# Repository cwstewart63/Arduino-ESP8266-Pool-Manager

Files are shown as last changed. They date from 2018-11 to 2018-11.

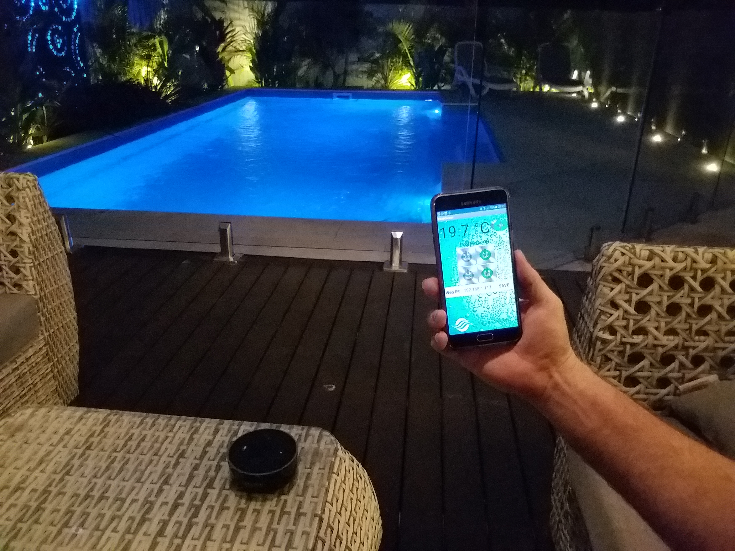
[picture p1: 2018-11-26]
MyPoolPic.jpg

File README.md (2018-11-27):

# Arduino-ESP8266-Pool-Manager
Pool manager with Phone App, Alexa, using Arduino and ESP8266

Project Summary:
This project is to allow remote control of my pool and associated lights with a dedicated display in the house, a phone application and Amazon Alexa. Any and/or all of these input devices may be used to control the pool. The pool temperature and the status of the control devices are monitored as additional information.

Folder Information:

123D Design: Contains Nextion 3.5" Display enclosure source file and .stl files of the bezel and base for 3D printing.
Note: the design uses M3 x 5mm brass inserts. 4 for the bezel, 4 for the base. Enclosure is sized to fit additional Modus Master PCB board which is the same size as the display using M3 x 6mm standoffs.

Alexa: Contains the AWS interaction model and the lambda function (python).
Note: Need to set up an Amazon AWS account and a developer account. lambda function needs to be updated with your thingspeak channel and key details

Arduino: Contains the Modbus Slave and Modbus Master source file and the ESP8266Modbus library.
Note: All code has been compiled using Arduino IDE Ver 1.8.4. Use the arduino IDE boards manager to install the ESP8266 range of boards.
This project has specifically used an Aduino nano for the Modbus Slave and an ESP8266 NodeMCU for the Modbus Master.
All libraries are standard as referenced with the excpetion of the ESP8266Modbus library which is the referenced Arduino Modbus library modified (ie just commented out specific Arduino references) so that it compiles in the ESP8266 environment.

MIT_AI2_PhoneApp: Contains the MIT App Inventor 2 project source and .apk file for android phone.
Note: Project can be converted to Thunkable if apple app is required. Note Port 81 has been explicitly used for the phone app server.

Nextion Display: Contains the nextion editor project source and the loadable .tft file for nextion
Note: This project uses the Nextion 3.5" enhance display with RTC for time / timer functions.

PCB Designs: Contains the PCB gerber files and Altium Circuitmaker source files for the Modbus Slave, Modbus Master, Astralpools VX Chlorinator interface board and an optional Valve power supply. The project uses a 24VAC 20VA transformer which will support one valve. If two valves are required then you can use this PCB design with a 24VAC 50VA transformer from the same manufacturer.
Note: All PCB designs were made using Altium Circuitmaker. I used breadboardkiller to manufacture the boards for me. Wiring schematics are included in case anyone wishes to reproduce their own boards.

Thingspeak: Note this project uses two thingspeak channels as the IOT interface for Amazon Alexa functionality, with the MQTT service for the publishing of status information and the subscibe service for the forwarding of Alexa command. The defualt in the code is for Alexa to be disabled. On configuration (ie. using Modbus Master board configuration pin), you enter your SSID, password details, along with the thinspeak channel details and tick the enable Alexa box.

Special thanks to those who provided the following libraries:

ModbusRTU: Samuel Marco i Armengol
https://github.com/smarmengol/Modbus-Master-Slave-for-Arduino

WiFi Manager: Ken Taylor
https://github.com/kentaylor/WiFiManager

Alexa Belkin Switch WEMO Emulator: Brian Lough
https://github.com/witnessmenow/esp8266-alexa-wemo-emulator

MQTT Client: Nick O'Leary
https://github.com/knolleary/pubsubclient

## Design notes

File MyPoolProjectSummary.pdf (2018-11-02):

# My Pool Project

## Contents

## Project Summary:

This project is to allow remote control of my pool and associated lights with a dedicated display in the house, a phone application and Amazon Alexa. Any and/or all of these input devices may be used to control the pool. The pool temperature and the status of the control devices are monitored as additional information.

The base system installed by the pool company consisted of an AstralPools VX chlorinator and a Viron P320 multispeed pump. To turn on the spa for example you had to go to the pool equipment enclosure and manually change the pool mode from “auto” to “on”, turn the valve to direct water to the spa, and manually set the pump speed to “high”.

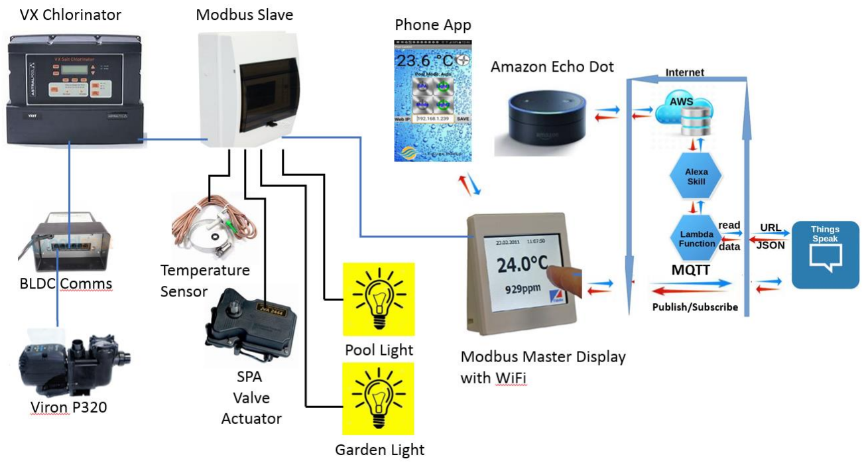
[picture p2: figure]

The schematic above shows the logical connectivity of the systems, which can be divided into three fundamental categories being, the standard Astralpools functionality, the Modbus Slave local control device and the Modbus Master remote display device.

## Standard AstralPools Functionality

The first stage of the project is to enable communication between the VX chlorinator and the Viron multispeed pump. This is achieved by the addition of the Viron BLDC communications module. Once installed you need to:
1. Enable “Fast Comms” on the Viron pump.
2. Enable “Fast Comms” on the VX chlorinator.
3. Select “3 speed pump enable” on the VX chlorinator.

Once this is done additional configuration menus on the VX chlorinator are shown which enable the operator to associate the desired pump speed with the mode of operation. In this case for normal chlorination (pool mode auto), then a low speed 1 is desired, while when spa operation (pool mode on) is requested, then high speed 3 is desired.
Note: The communications between the VX chlorinator and viron pump in Australia is not MODBUS. Although Astralpools in Europe does support the viron pump with MODBUS, the Australian version is a proprietary protocol.

## MODBUS Slave Local Control Device

The local control device is installed in the pool equipment enclosure adjacent to the VX chlorinator and viron pool pump. This device is essentially a Arduino Nano microcontroller which supports the inputs (temperature and pool status) and the digital outputs for the valves and lights. The microcontroller is also programmed as a Modbus slave for communication to the Modbus master display controller.
The microcontroller is programmed using the Arduino IDE software on windows.

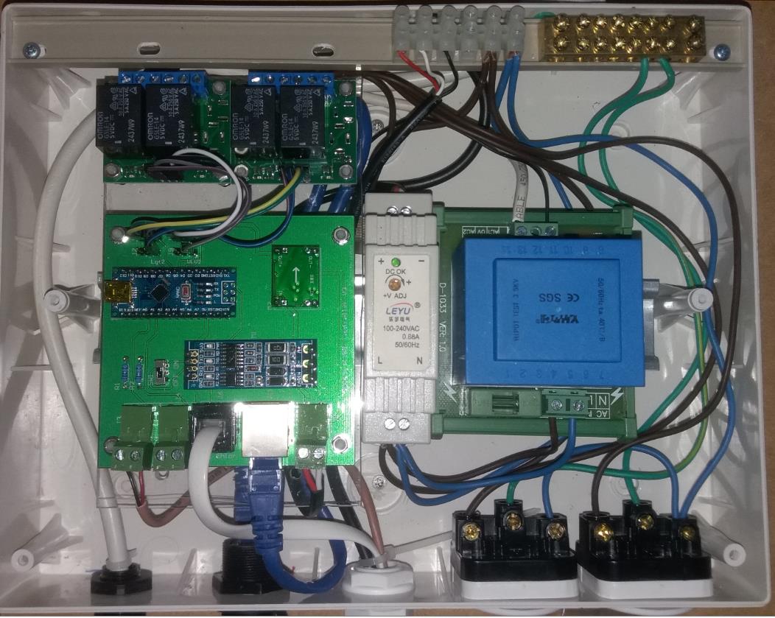
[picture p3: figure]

The major components of the Modbus slave local controller include:
1. Arduino Nano microcontroller PCB
2. 24VDC power supply (power for both local controller, interface module and remote display controller)
3. 24VAC power supply for Jandy valve actuator
4. 4 x Relay modules for the valve and lights control
5. A standard 12 pole IP54 electrical enclosure with DIN rail mounting
6. 2 x panel mounted electrical sockets for the light connections.

In addition there is a VX Chlorinator interface module PCB (below) which is installed into the chlorinator itself to provide the local I/O control and connected to the Modbus slave local controller via a standard RJ12 six core cable.

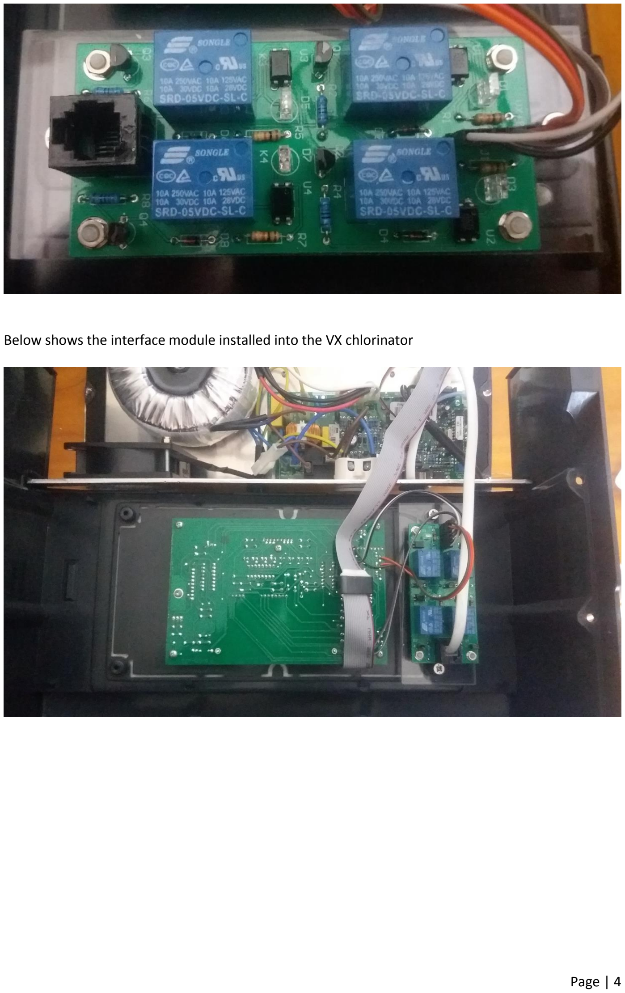
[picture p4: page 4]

Below shows the interface module installed into the VX chlorinator

## MODBUS Master Remote Display Device

The Remote display device is a 3.5 inch Nextion touch screen mounted into a custom 3D printed enclosure to house the touch screen and the Modbus master PCB. Power and communications are provided by a standard RJ45 CAT5e network cable connected to the Modbus slave controller. Modbus communications are via one pair of the CAT5e cable using RS485 communication modules with two pairs being used for the 24VDC power.

The display allows the remote monitoring and control of all the connected pool devices. In addition the display also has two timers associated with the lights to enable automatic on/off control of the lights. The timers in the VX Chlorinator are still used for the automatic control of the pool chlorination.

The Modbus master display uses a ESP8266 NodeMCU microcontroller programmed as a Modbus master device for communication to the Modbus slave. The ESP8266 NodeMCU also supports WiFi connectivity, with the provision of web/client services to support both the mobile phone application, and Amazon Alexa functionality.

The Modbus master PCB has been sized to match that of the Nextion 3.5” display so that it can be attached together via standoffs and mounted together into the custom 3D printed housing. The housing is a similar size to a standard electrical outlet with identical mounting holes so that standard electrical mounting plates can be used for fixing.

The microcontroller is programmed using the Arduino IDE software on windows.
The major components of the Modbus master display controller include:
1. ESP8266 NodeMCU microcontroller PCB
2. Nextion 3.5” touch display
3. Custom 3D printed wall mount enclosure

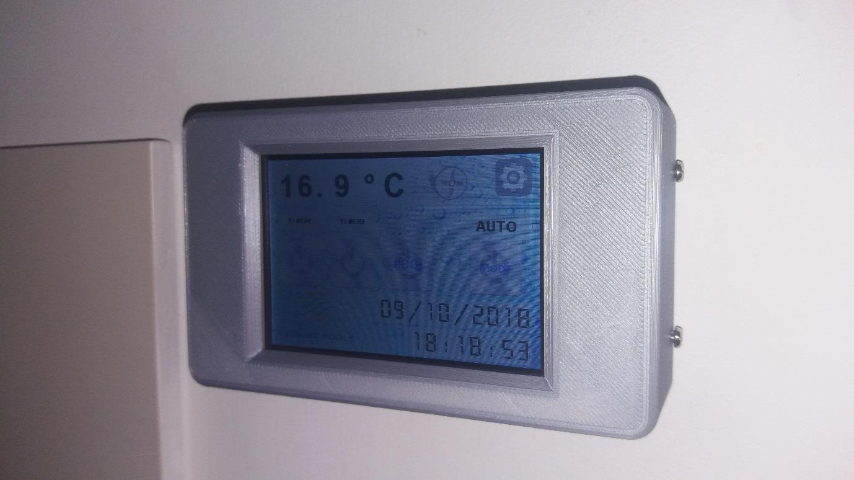
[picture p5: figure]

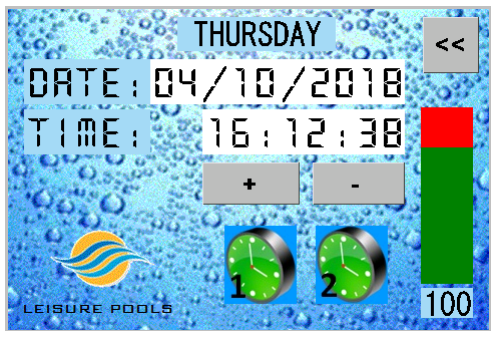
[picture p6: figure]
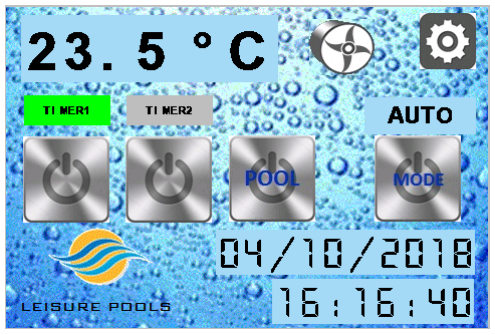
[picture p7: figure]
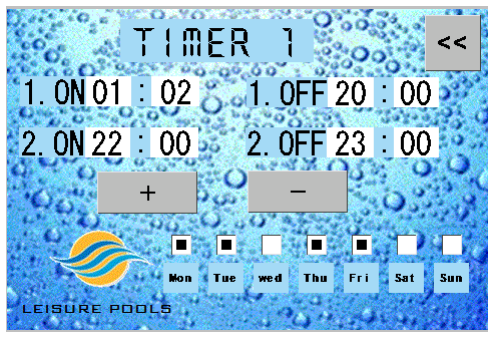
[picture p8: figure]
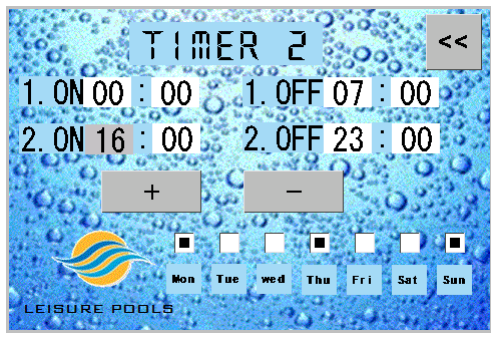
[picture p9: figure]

## Mobile Phone App

The ESP8266 NodeMCU microcontroller also runs a webserver to support the mobile phone application client. This supports the same monitoring and control functionality as the dedicated display with the exception of the additional automatic timers.

The mobile phone application was made using the MIT App Inventor 2 software, which supports applications for android devices and can be added for download on the google playstore.
If the user wants an application for apple phones the same code can be used with the Thunkable software (ie the same owner as MIT App Inventor 2). Thunkable applications can be used on both android and apple phones.

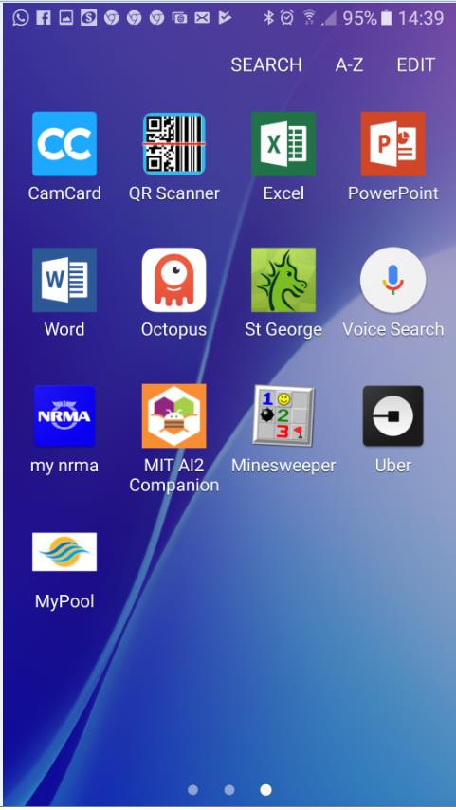
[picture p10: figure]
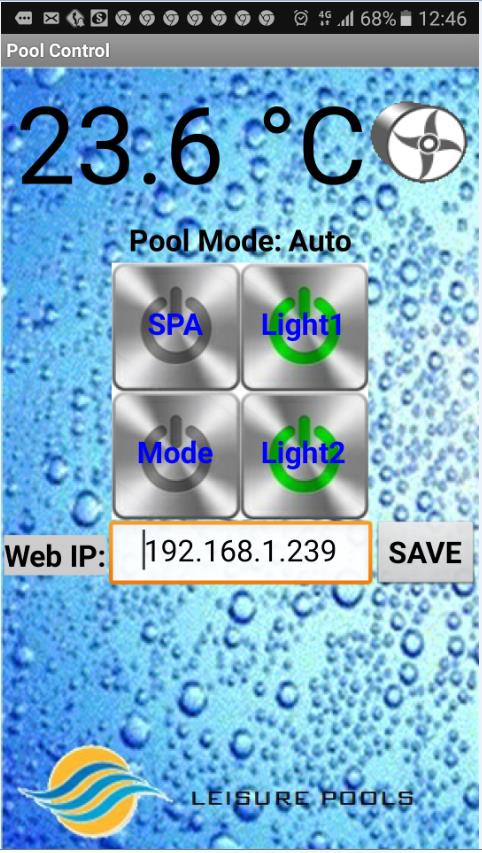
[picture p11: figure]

## Amazon Alexa Echo

The ESP8266 NoneMCU microcontroller also runs webservers / clients to support the Alexa functionality. This is separated into two parts. The first part is a Belkin switch device emulator which allows Alexa to directly control the spa, pool lights and garden lights. With the Modbus Master controller powered and connected to the home wifi and internet, then upon Alexa device discovery then the three above devices are automatically added to Alexa.

For example:
User asks:
“Alexa, turn the spa on”
Alexa Response:
“ok”, The spa valve will go to the spa position.

The second part of the Alexa functionality is for the reporting of the pool status information. This status information is sent to the thingspeak IOT service every 1 minute (configurable) via the MQTT publish service . The custom Alexa skill then interacts with the thingspeak IOT to respond to Alexa requests for information. The Pool Mode commands are sent to the Modbus master controller via the MQTT subscribe service.

For example:
User asks:
“Alexa, ask my pool, check the status”
Alexa Response:
“The temperature is 25.5 celsius. Mode is auto. Spa if off. Pump is on.”

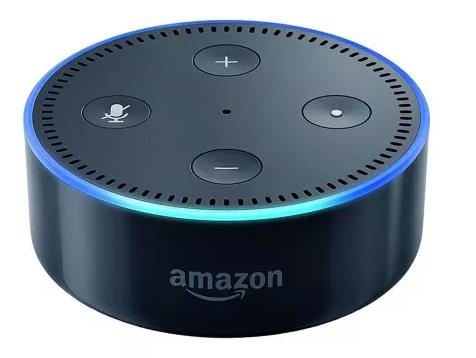
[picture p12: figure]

Configuration by the user of the local wifi SSID and password details, as well as the thingspeak settings to enable the Alexa functionality is achieved via a dedicated wifi manager which is initiated by a pushbutton at the back of the Modbus Master controller.

This puts the ESP8266 Wifi into a dedicated access point mode which serves a configuration page on the 192.168.4.1 IP address. The user simply accesses this page using any browser in a computer or mobile phone and enters the configuration data. The system automatically scans for available wifi networks, so the user can simply select their wifi and enter the password information.
At this point the user can also enter the thingspeak configuration details and enable the Alexa functionality for use.
Note the Alexa functionality should only be enabled if the thingspeak account has been fully setup.

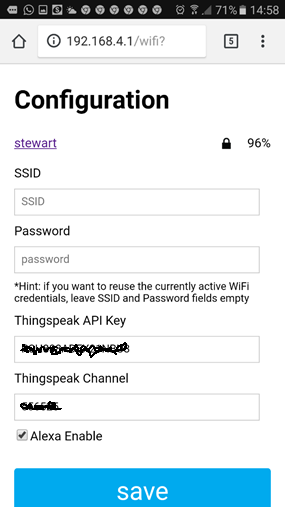
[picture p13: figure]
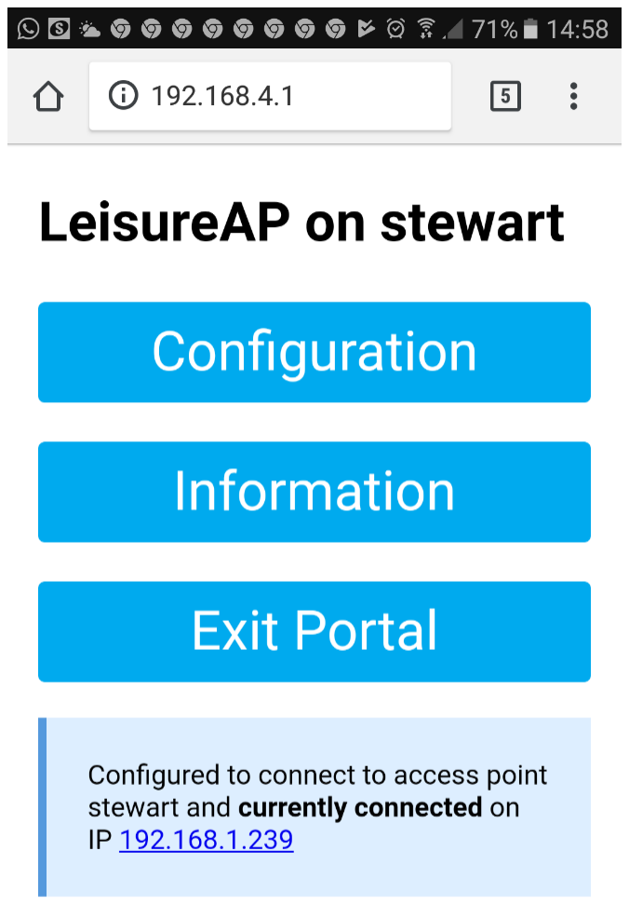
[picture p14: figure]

## Major Component List:

Item | Description | QTY
1 | Modus Slave Controller PCB – Refer to schematic diagram | 1
2 | VX Chlorinator Interface PCB - Refer to schematic diagram | 1
3 | 24 VDC-15W Power Supply https://www.aliexpress.com/store/product/Din-Rail-series-DR-15-24V-AC-24VDC-single-output-high-quality-led-switching-power-supply/509864_32773686204.html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 df47haA9um (https://www.aliexpress.com/store/product/Din-Rail-series-DR-15-24V-AC-24VDC-single-output-high-quality-led-switching-power-supply/509864_32773686204.html) | 1
4 | 24 VAC-20VA Power Supply https://www.aliexpress.com/item/P-230VAC-S-24VAC-20VA-DIN- Rail-Mount-Power-Transformer-Module-D-1033T-R- AC24V/32311212639.html?spm=2114.search0104.3.31.XZ4q3d&w s_ab_test=searchweb0_0,searchweb201602_2_5460015_10152_1 0065_10151_10130_10068_10344_5560015_10342_10343_10340 _10341_5470015_10307_10137_10060_10131_10155_10132_101 33_10154_10056_10055_10054_10059_100031_10099_10338_10 339_5380015_10103_10102_440_10052_10053_10050_10107_10 142_10051_10326_10084_10083_10080_10082_10081_10110_10 175_10111_10112_10113_10114_143_10312_10313_10314_5570 015_10078_10079_10073_5550015,searchweb201603_2,ppcSwitc h_3&btsid=f29743f2-92d7-4487-a3c2- 684a69d7a7ad&algo_expid=69a75a8c-997e-4cf4-b7db- 38b3bc45df85-4&algo_pvid=69a75a8c-997e-4cf4-b7db- 38b3bc45df85 (https://www.aliexpress.com/item/P-230VAC-S-24VAC-20VA-DIN-Rail-Mount-Power-Transformer-Module-D-1033T-R-AC24V/32311212639.html)

1

5 | 5VDC – 2 Channel Relays https://core-electronics.com.au/pololu-basic-2-channel-spdt-relay-carrier-with-5vdc-relays-assembled.html (https://core-electronics.com.au/pololu-basic-2-channel-spdt-relay-carrier-with-5vdc-relays-assembled.html) | 2

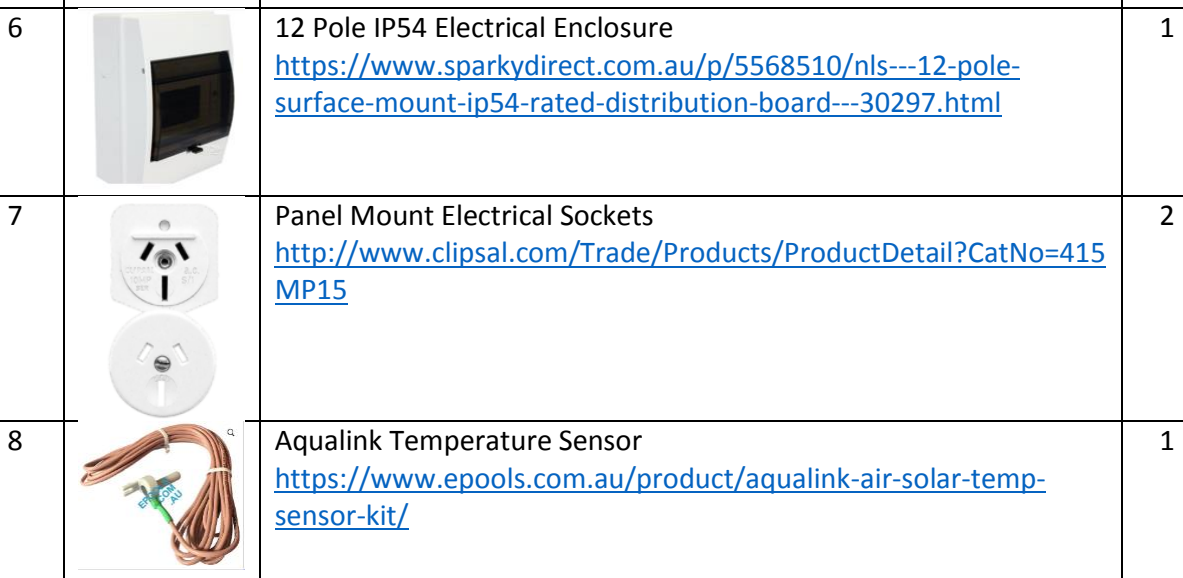
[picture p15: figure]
Aqualink Temperature Sensor https://www.epools.com.au/product/aqualink-air-solar-temp-sensor-kit/ (https://www.epools.com.au/product/aqualink-air-solar-temp-sensor-kit/)

6 | 12 Pole IP54 Electrical Enclosure https://www.sparkydirect.com.au/p/5568510/nls---12-pole-surface-mount-ip54-rated-distribution-board---30297.html (https://www.sparkydirect.com.au/p/5568510/nls---12-pole-surface-mount-ip54-rated-distribution-board---30297.html) | 1
7 | Panel Mount Electrical Sockets http://www.clipsal.com/Trade/Products/ProductDetail?CatNo=415 MP15 (http://www.clipsal.com/Trade/Products/ProductDetail?CatNo=415MP15) | 2
9 | Jandy 24VAC Valve Actuator https://www.bestpoolsupplies.com.au/product/805/Jandy-Zodiac-Valve-Actuator (https://www.bestpoolsupplies.com.au/product/805/Jandy-Zodiac-Valve-Actuator) | 1
10 | RJ12 Cable – 6P6C, 3 m | 1

11 | Astralpool Viron BLDC Pump Comms https://www.poolspot.com.au/astralpool-viron-bldc-pump-comms-box-interface-module-no-cables (https://www.poolspot.com.au/astralpool-viron-bldc-pump-comms-box-interface-module-no-cables)
12 | Modbus Master Controller PCB – Refer to schematic diagram | 1

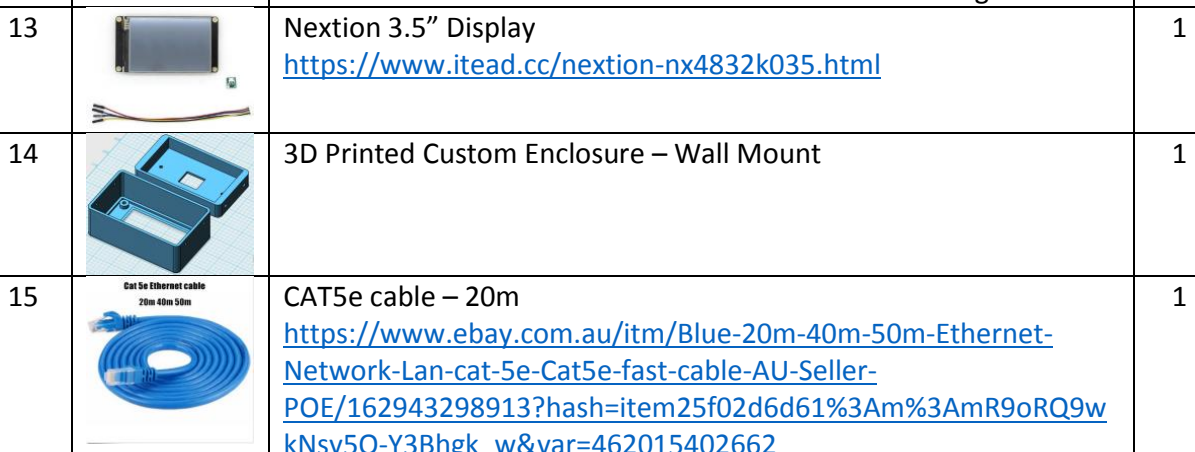
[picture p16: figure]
Nextion 3.5” Display https://www.itead.cc/nextion-nx4832k035.html

14 | 3D Printed Custom Enclosure – Wall Mount | 1
15 | CAT5e cable – 20m https://www.ebay.com.au/itm/Blue-20m-40m-50m-Ethernet-Network-Lan-cat-5e-Cat5e-fast-cable-AU-Seller-POE/162943298913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 (https://www.ebay.com.au/itm/Blue-20m-40m-50m-Ethernet-Network-Lan-cat-5e-Cat5e-fast-cable-AU-Seller-POE/162943298913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) | 1
16 | DIN Rail Bracket https://www.ebay.com.au/itm/DIN-Rail-Mount-Bracket-Equipment-Rack-G3NE-Electrical-for-SSR-R99-12-Fins/222613815002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: 6ZoAAOSwqbxZ8ALX:rk:10:pf:0 (https://www.ebay.com.au/itm/DIN-Rail-Mount-Bracket-Equipment-Rack-G3NE-Electrical-for-SSR-R99-12-Fins/222613815002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) | 1
17 | Perspex Sheet 3mm https://www.ebay.com.au/itm/Clear-Acrylic-Perspex-Sheet-2-Pack-A4-Size-297mm-x-210mm-x-3mm/221572093277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 (https://www.ebay.com.au/itm/Clear-Acrylic-Perspex-Sheet-2-Pack-A4-Size-297mm-x-210mm-x-3mm/221572093277) | 1

### Modbus Slave Controller PCB Components:

Designator | Description | QTY
J2 | Phoenix 1757242 MSTBA 2.5/ 2-G-5.08 Base Strip/Header 4 Kilo-Volt Surge 320 Volt Rated III/2 12 Amp Green Plug-In | 1
J3 | Phoenix 1757242 MSTBA 2.5/ 2-G-5.08 Base Strip/Header 4 Kilo-Volt Surge 320 Volt Rated III/2 12 Amp Green Plug-In | 1
J4 | Phoenix 1757242 MSTBA 2.5/ 2-G-5.08 Base Strip/Header 4 Kilo-Volt Surge 320 Volt Rated III/2 12 Amp Green Plug-In | 1
J6 | RJ11 6P6C Telephone Cable Socket | 1
J7 | 2.54mm (0.1") Pitch SIL Vertical PC Tail Pin Header, 6.1mm mating pin height, gold (hi-temp mould), 3 contacts | 1
J8 | 2.54mm (0.1") Pitch SIL Vertical PC Tail Pin Header, 6.1mm mating pin height, gold (hi-temp mould), 3 contacts | 1
J9 | 2.54mm (0.1") Pitch SIL Vertical PC Tail Pin Header, 6.1mm mating pin height, gold (hi-temp mould), 3 contacts | 1
J10 | 2.54mm (0.1") Pitch SIL Vertical PC Tail Pin Header, 6.1mm mating pin height, gold (hi-temp mould), 3 contacts | 1
J11 | Socket; RJ45; PIN: 8; Cat: 5e; shielded; gold plated; THT; angled 90° | 1
M1 | RS485 Module with auto flow control https://www.ebay.com.au/itm/TTL-to-RS485-Module-Serial-Port-UART-Hardware-Automatic-Flow-Control-NEW-AU/302554547091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 (https://www.ebay.com.au/itm/TTL-to-RS485-Module-Serial-Port-UART-Hardware-Automatic-Flow-Control-NEW-AU/302554547091) | 1
M2 | MP1564EN Buck Converter Board https://www.ebay.com.au/itm/Mini-Step-Down-Module-DC-DC-Converter-Input-7V-28V-Output-5V-3A-Replace-LM2596/263005707656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 (https://www.ebay.com.au/itm/Mini-Step-Down-Module-DC-DC-Converter-Input-7V-28V-Output-5V-3A-Replace-LM2596/263005707656) | 1
MCU | Arduino Nano https://www.ebay.com.au/itm/USB-Nano-V3-0-ATMEGA328P-CH340G-5V-16M-Micro-Controller-Board-Kit-FOR-Arduino/263004104622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 (https://www.ebay.com.au/itm/USB-Nano-V3-0-ATMEGA328P-CH340G-5V-16M-Micro-Controller-Board-Kit-FOR-Arduino/263004104622) | 1
R1, R2 | Resistor; Carbon Composition; Res 10K Ohms; Pwr-Rtg 0.25 W; Tol 1%; Axial | 2
SW1 | JS Series DPDT On-On PC Pin Through Hole Subminiature Slide Switch | 1

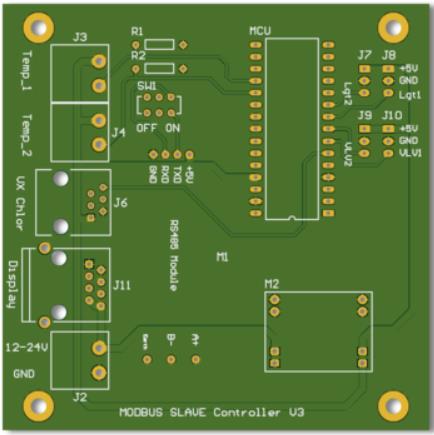
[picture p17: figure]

### VX Chlorinator Interface Module PCB Components:

Designator | Description | QTY
D1, D3, D5, D7 | LED | 4
D2, D4, D6, D8 | 1N4148 Diode | 4
J1 | Header HDR 7 POS 2.54mm Solder ST Thru-Hole Bag | 1
J2 | Socket 6P6C Telephone Cable | 1
K1, K2, K3, K4 | SONGLE SRD-05VDC-SL-C | 4
Q1, Q2, Q3, Q4 | BC547/PN100 Transistor | 4
R1, R3, R5, R7 | 'Resistor; Metal Film; Res 1 Kilohms; Pwr-Rtg 0.25 W; Tol 5%; Axial; TCR 15 ppm/DegC | 4
R2, R4, R6, R8 | Resistor; Metal Film; Res 510 ohms; Pwr-Rtg 0.25 W; Tol 5%; Axial; TCR 15 ppm/DegC | 4
U1, U2, U3, U4 | 'LTV-817 Series Single Channel 35 V 5000 Vrms Transistor Output Optocoupler - DIP-4 | 4

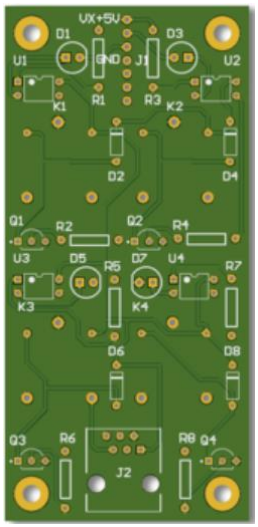
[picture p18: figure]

### Modbus Master Controller PCB Components:

Designator | Description | QTY
D1 | Blue LED, Through Hole package | 1
J1 | Header Shrouded 4 Position 5.08 mm Pitch Euro Style Terminal Block | 1
J2 | 4 pin right angle header | 1
J3 | 4 pin right angle header | 1
J4 | AMPMODU 1 Position 2.54 mm Single Row Through Hole Straight Header | 1
M1 | RS485 Module with auto flow control https://www.ebay.com.au/itm/TTL-to-RS485-Module-Serial-Port-UART-Hardware-Automatic-Flow-Control-NEW-AU/302554547091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 (https://www.ebay.com.au/itm/TTL-to-RS485-Module-Serial-Port-UART-Hardware-Automatic-Flow-Control-NEW-AU/302554547091) | 1
M2 | MP1564EN Buck Converter Board https://www.ebay.com.au/itm/Mini-Step-Down-Module-DC-DC-Converter-Input-7V-28V-Output-5V-3A-Replace-LM2596/263005707656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 (https://www.ebay.com.au/itm/Mini-Step-Down-Module-DC-DC-Converter-Input-7V-28V-Output-5V-3A-Replace-LM2596/263005707656) | 1
R1 | Resistor; Metal Film; Res 330 ohms; Pwr-Rtg 0.25 W; Tol 1%; Axial; TCR 15 ppm/DegC | 1
SW1 | JS Series DPDT On-On PC Pin Through Hole Subminiature Slide Switch | 1
SW2 | Switch Tactile OFF (ON) SPST Round Button PC Pins 0.05A 24VDC 100000Cycles 2.55N Thru-Hole Loose | 1
U | NodeMCU V2 Featuring ESP-12E https://www.ebay.com.au/itm/NodeMcu-Lua-WIFI-Internet-Things-development-board-based-ESP8266-CP2102-Arduino/262660551222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 (https://www.ebay.com.au/itm/NodeMcu-Lua-WIFI-Internet-Things-development-board-based-ESP8266-CP2102-Arduino/262660551222) | 1

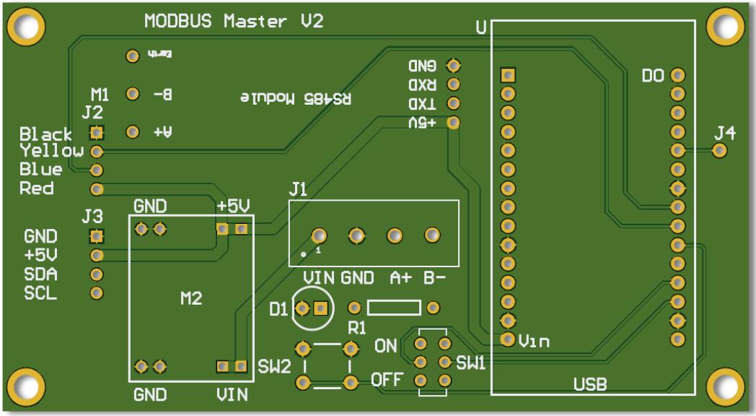
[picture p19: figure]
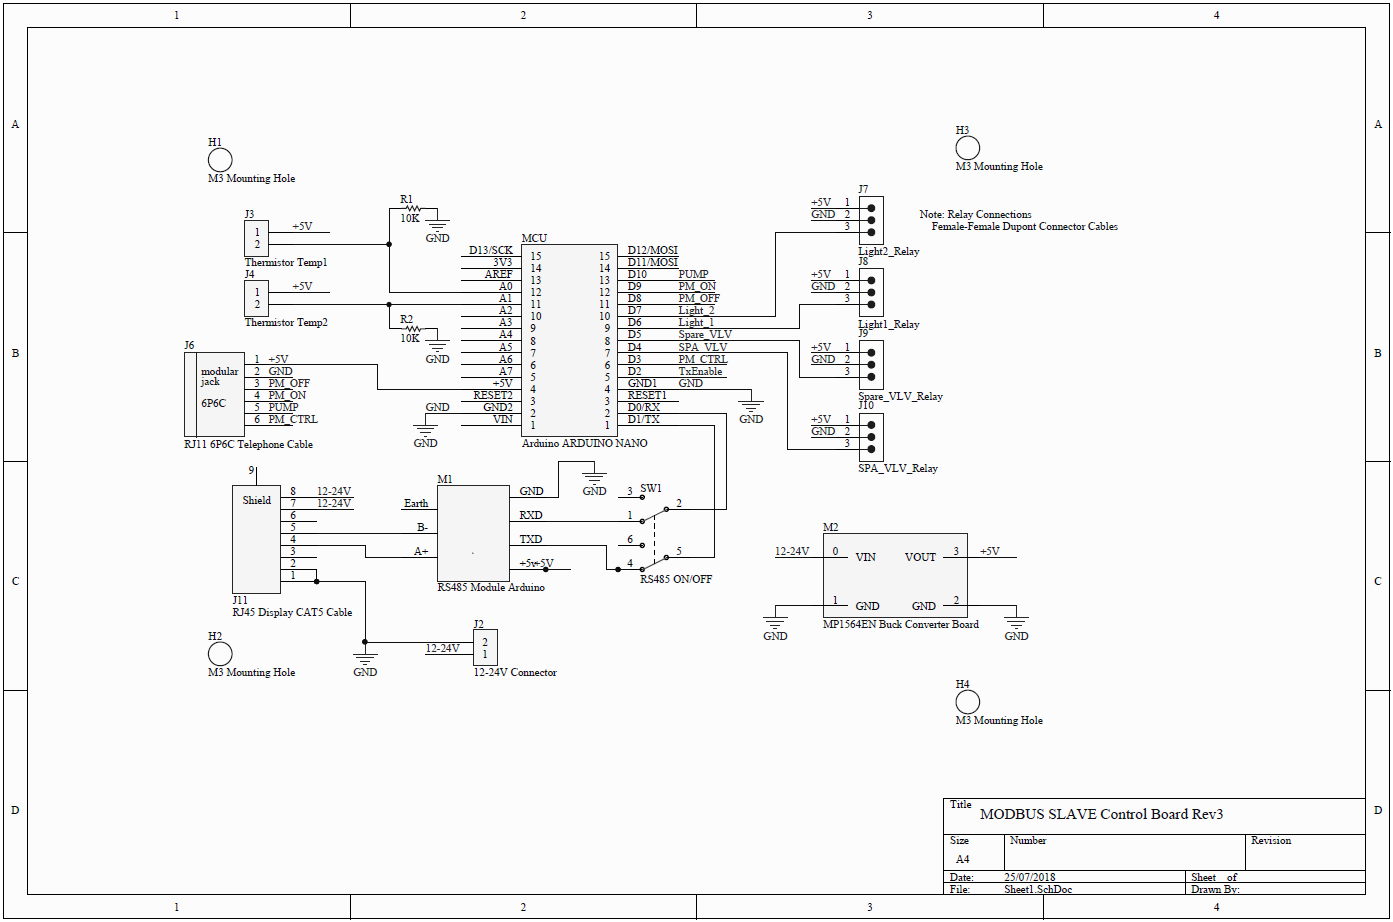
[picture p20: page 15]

Page | 15

### Modbus Slave Schematic

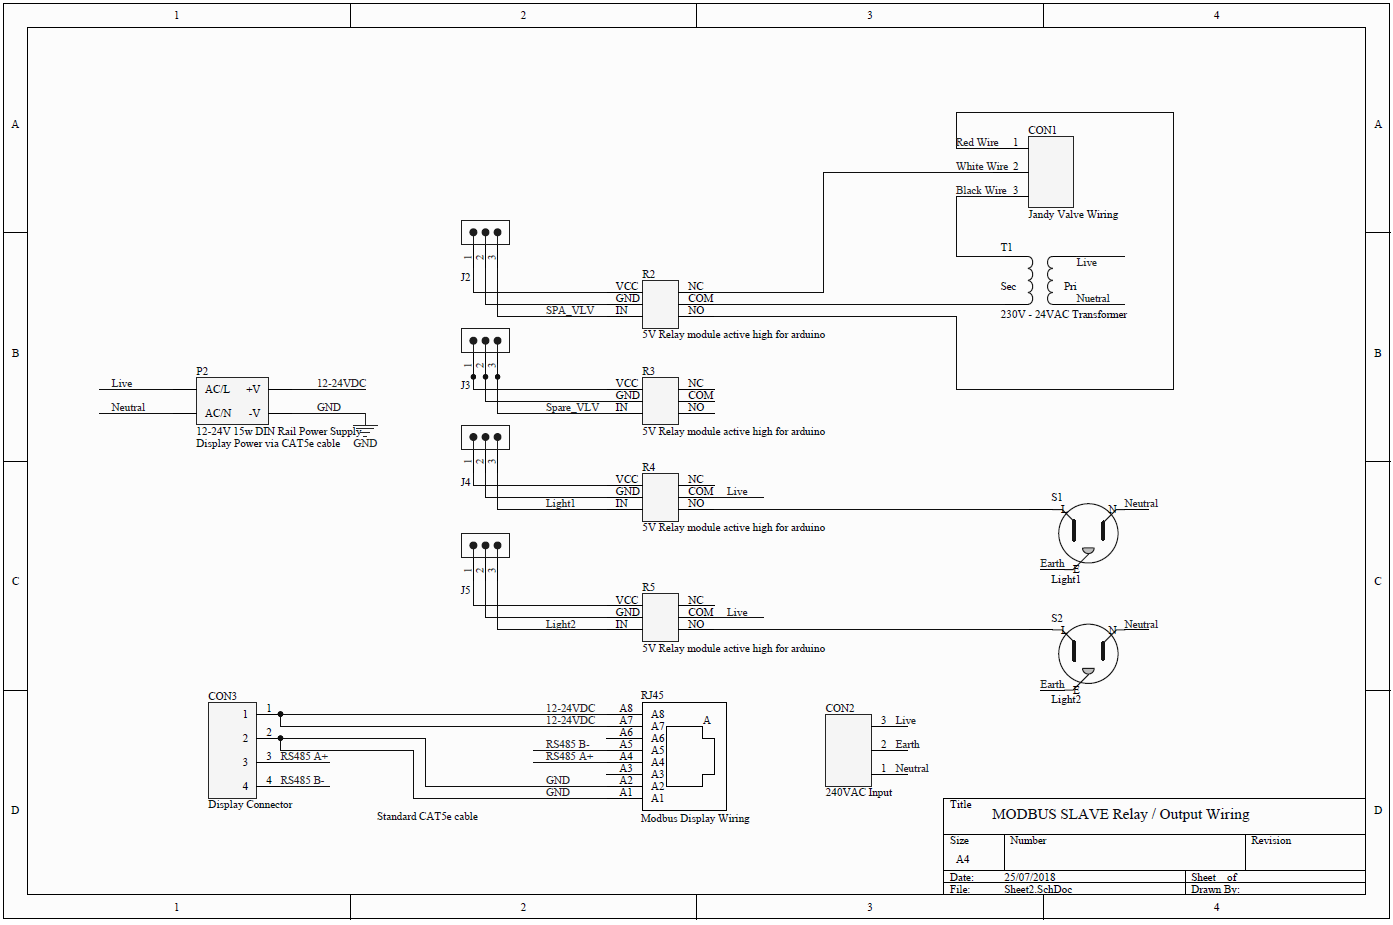
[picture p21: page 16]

Page | 16

### Modbus Slave Relay / Output Wiring

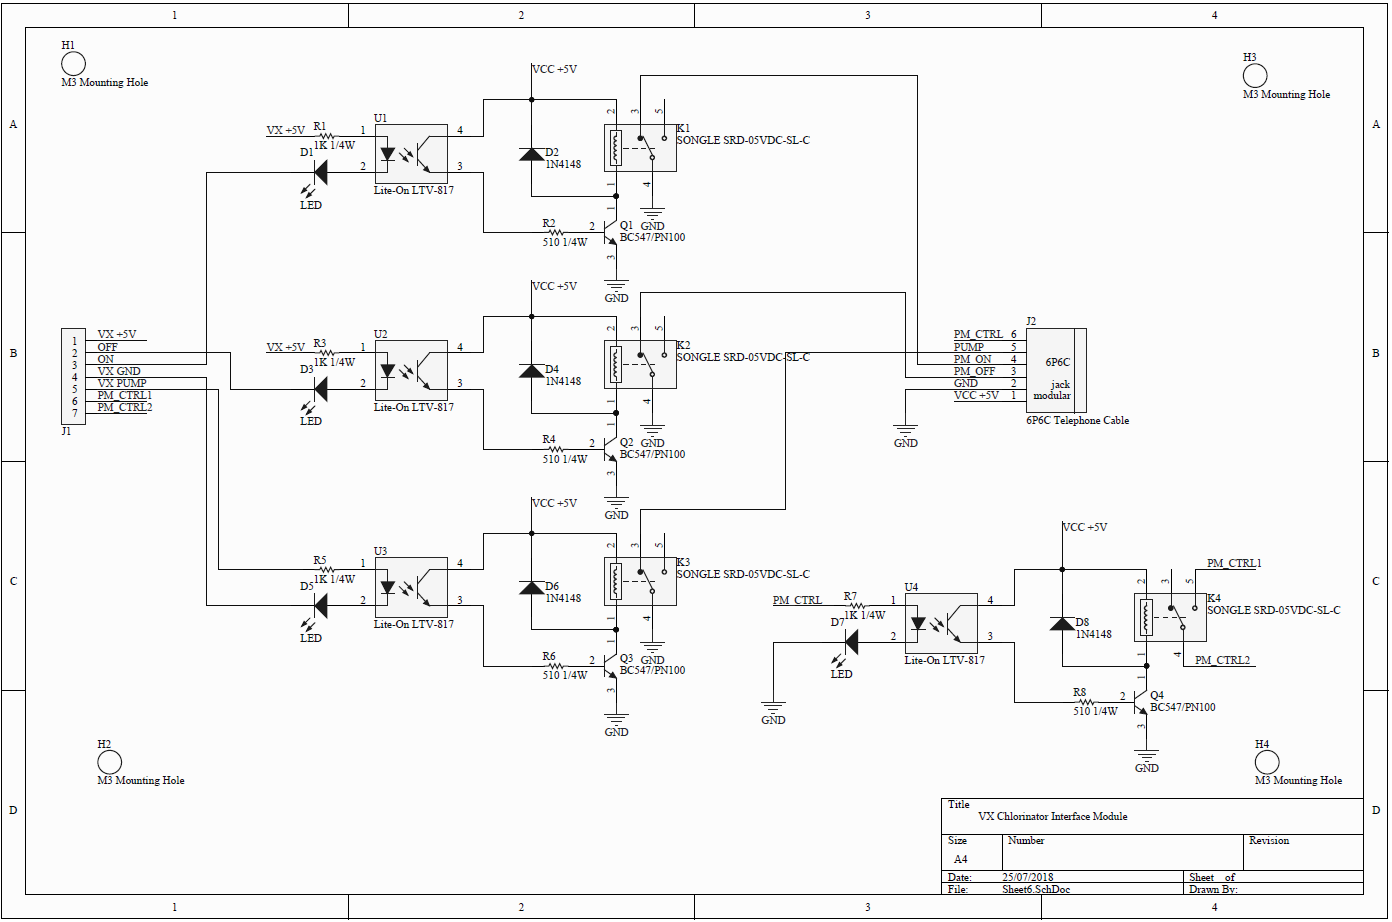
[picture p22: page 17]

Page | 17

### VX Chlorinator Interface Module

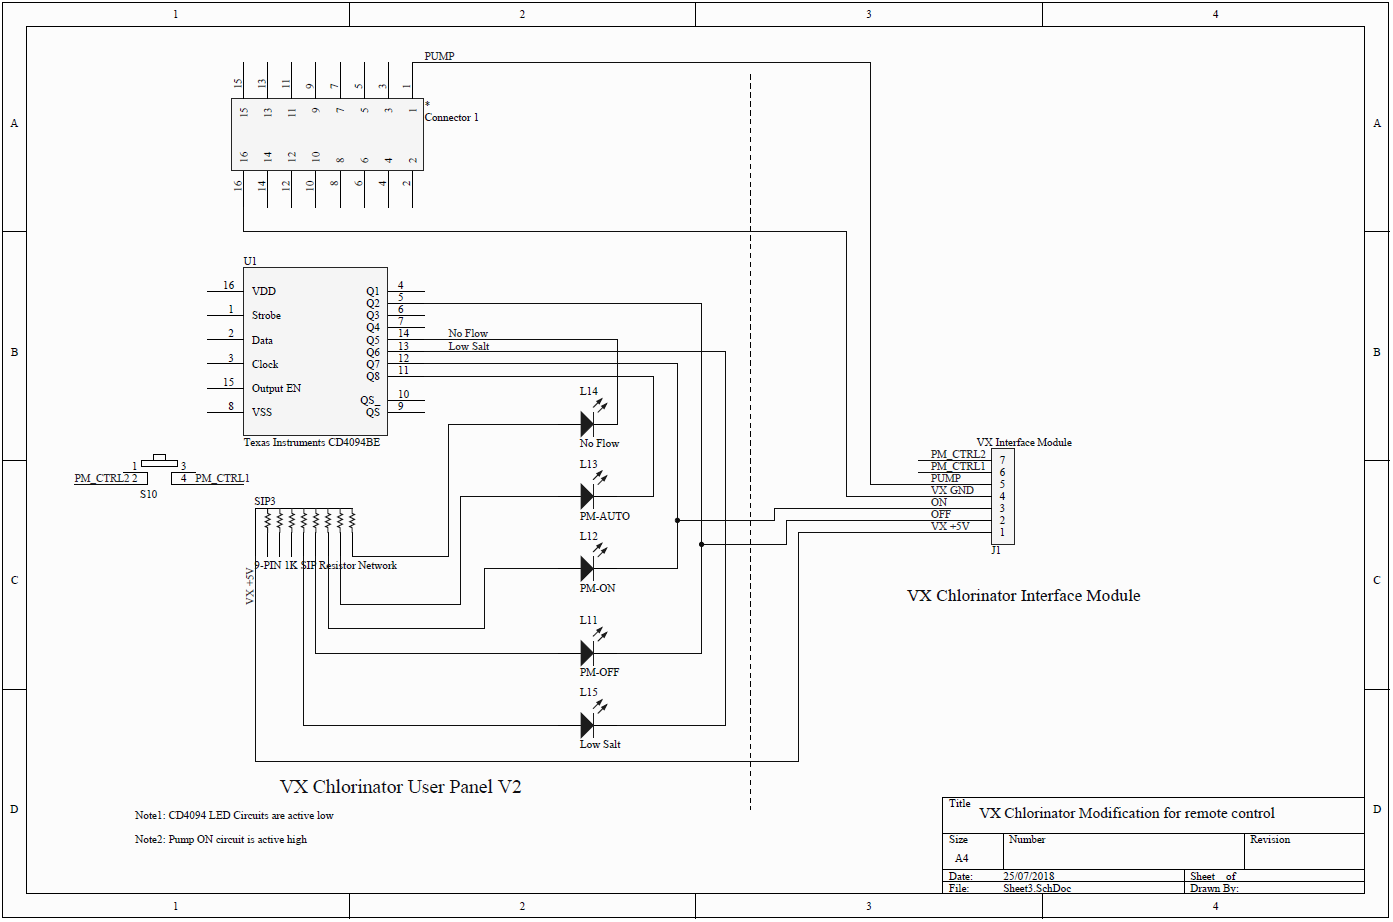
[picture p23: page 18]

Page | 18

### VX Chlorinator Interface Connection Wiring

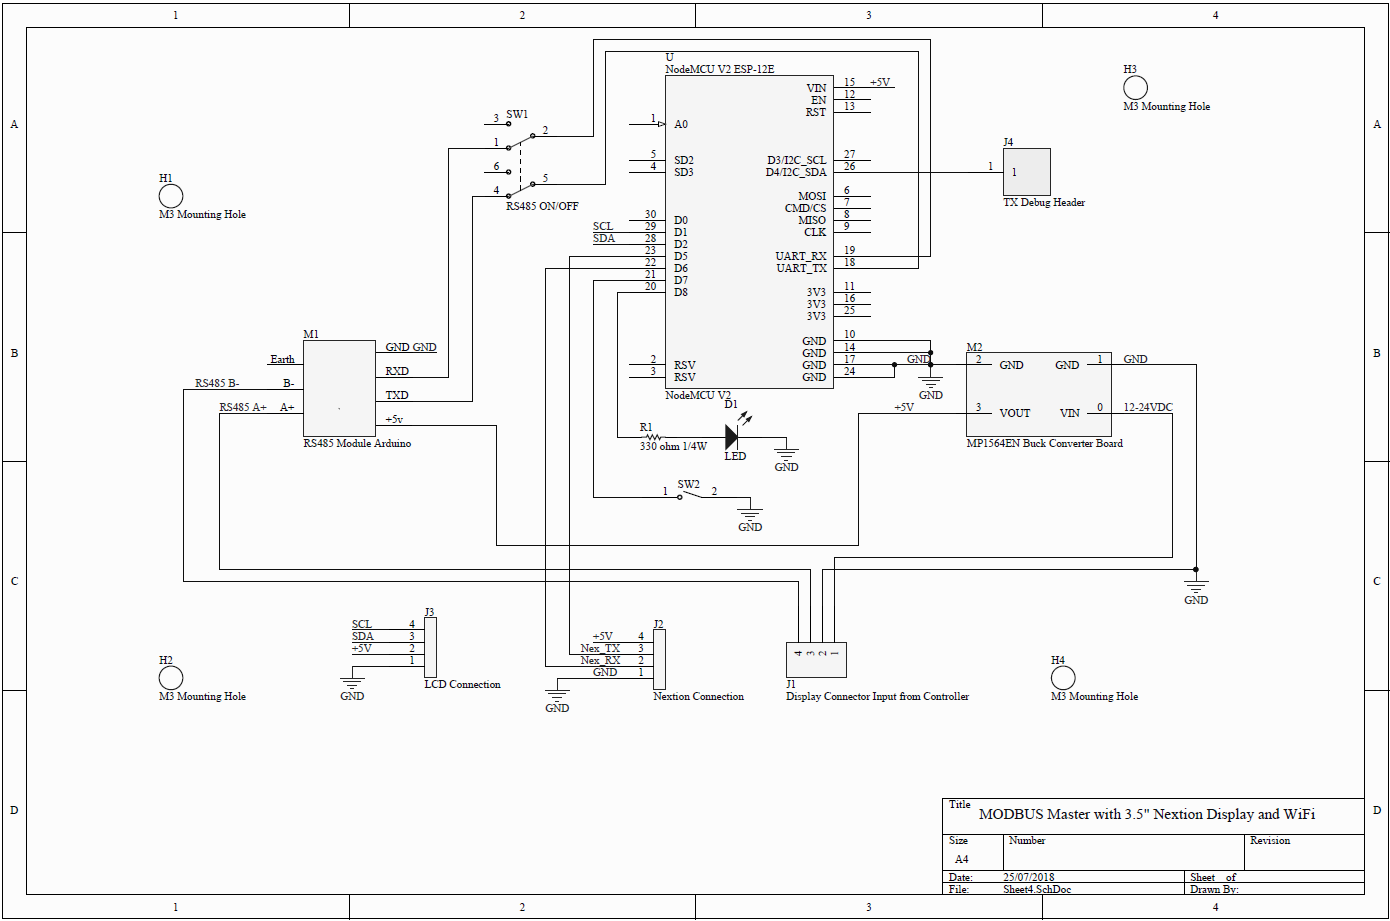
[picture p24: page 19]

Page | 19

### Modbus Master with 3.5” Nextion Display and WiFi

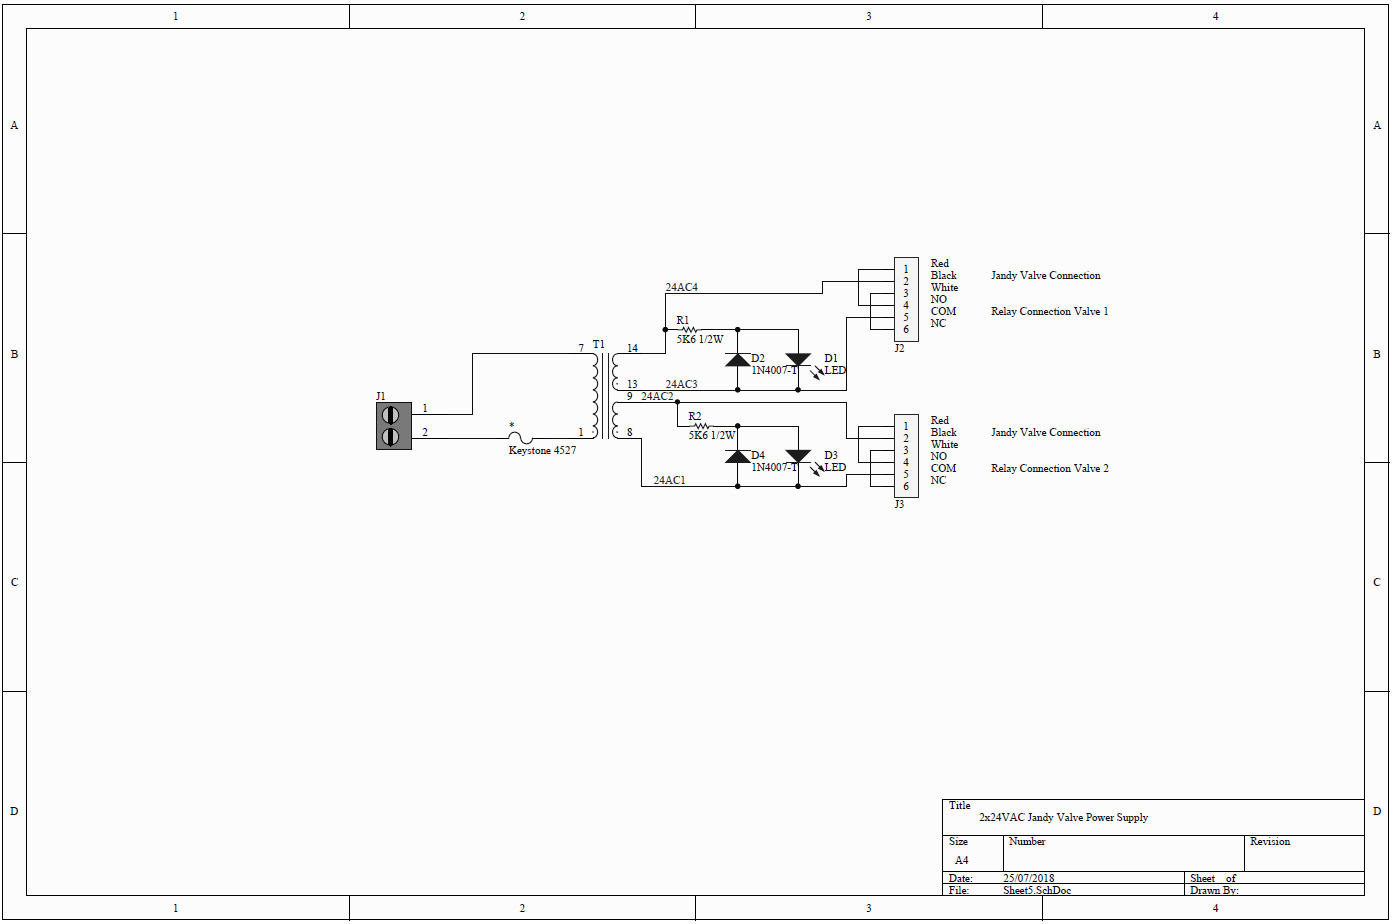
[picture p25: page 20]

Page | 20

### Power Supply for 2 x 24VAC Jandy Actuators

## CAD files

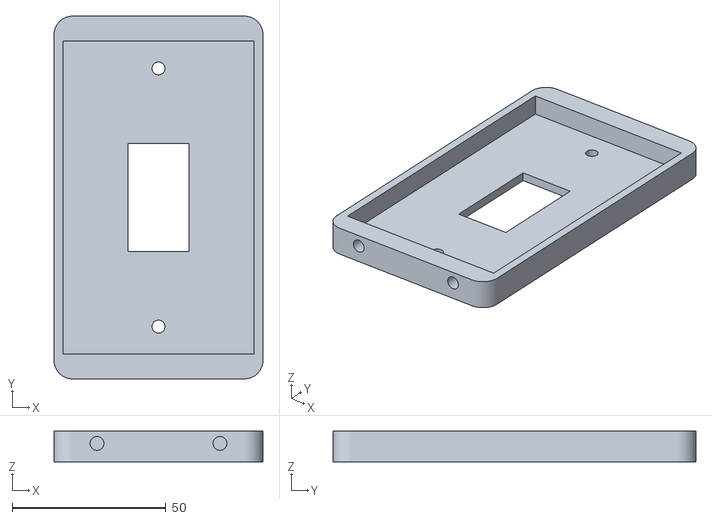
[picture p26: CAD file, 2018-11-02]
123D Design/Base_with_brass_M3_inserts.stl
68.0 x 118.0 x 10.0

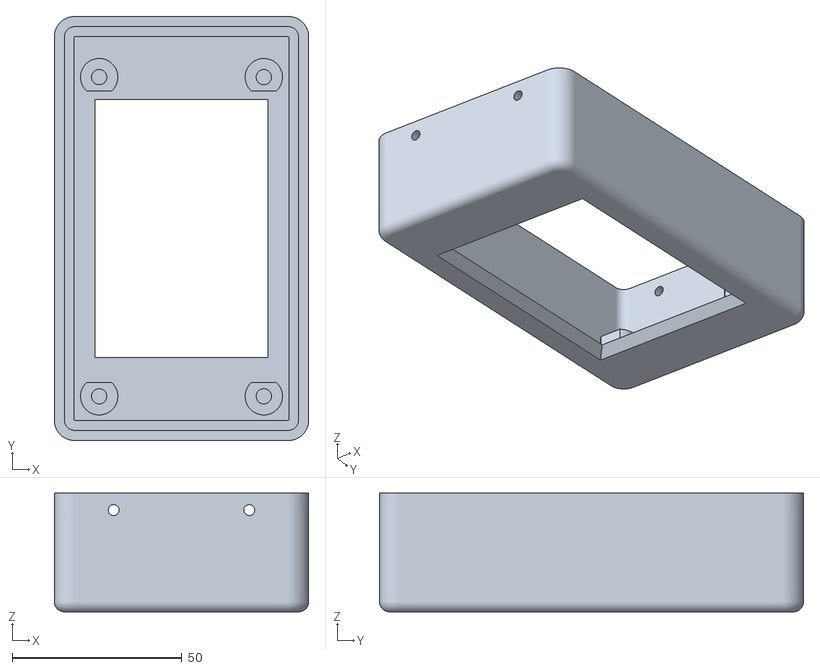
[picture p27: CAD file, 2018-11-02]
123D Design/Bezel_with_brass_M3_inserts.stl
75.0 x 125.0 x 35.0

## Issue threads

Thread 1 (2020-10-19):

Additional information

farsonic, 2020-10-19:
Hi there,

I have this exact combination of pump and chlorinator. Can you help confirm how this is wired up....there is a Astralpools VX Chlorinator interface board that you have designed. Does this need to be installed in the chlorinator or does it replace an existing piece? How is it connected? There is very few details here ... I'm happy to update the github repo as I go.

cdk222, 2021-01-18:
@farsonic

Did you have any luck with Astral? I am also very keen on this but just getting started. Any thoughts on whether could use other existing modbus boards\shields to add to the arduino instead of having to create own PCB board

farsonic, 2021-01-18:
nope...not a word back from Astral.....

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

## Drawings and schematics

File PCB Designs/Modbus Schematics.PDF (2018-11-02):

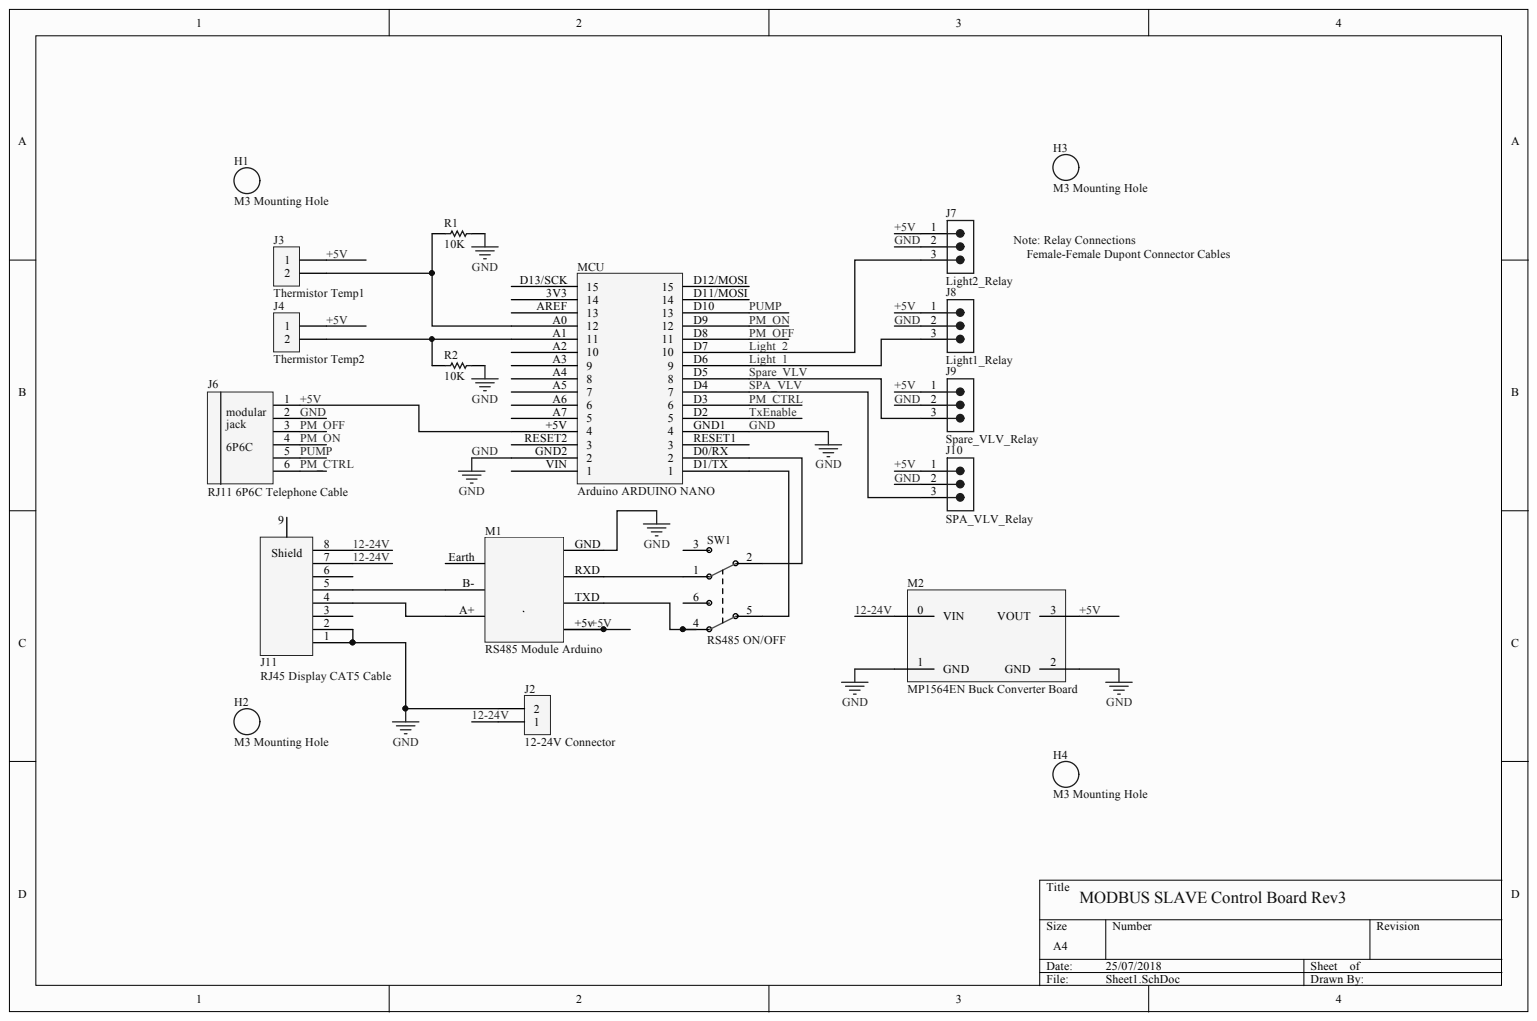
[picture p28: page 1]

Note: Relay Connections
Female-Female Dupont Connector Cables

SPA_VLV PM_CTRL

2 | GND | TxEnable GND

Title
MODBUS SLAVE Control Board Rev3

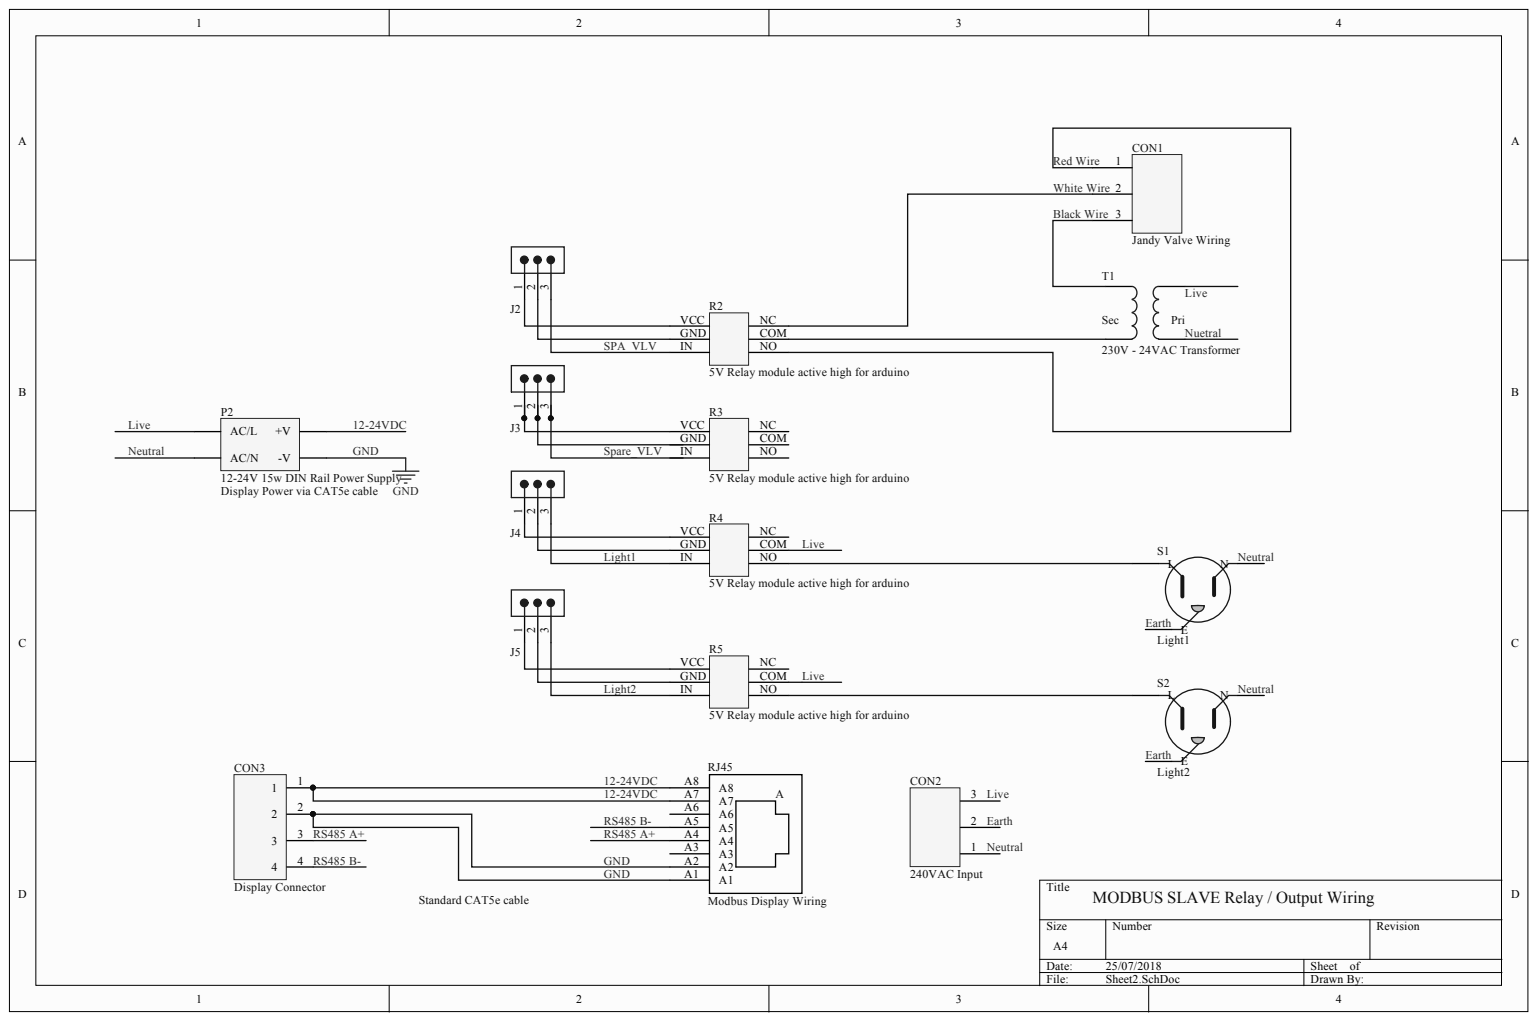
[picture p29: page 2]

Black Wire | 3

GND | COM

SPA_VLV | IN | NO

5V Relay module active high for arduino

12-24V 15w DIN Rail Power Supply

GND

Light1 | IN

Light2 | IN
A1 A1 A2 A2 A3 A3 A4 A4 A5 A5 A6 A6 A7 A7 A8 A8

12-24VDC

Title
MODBUS SLAVE Relay / Output Wiring

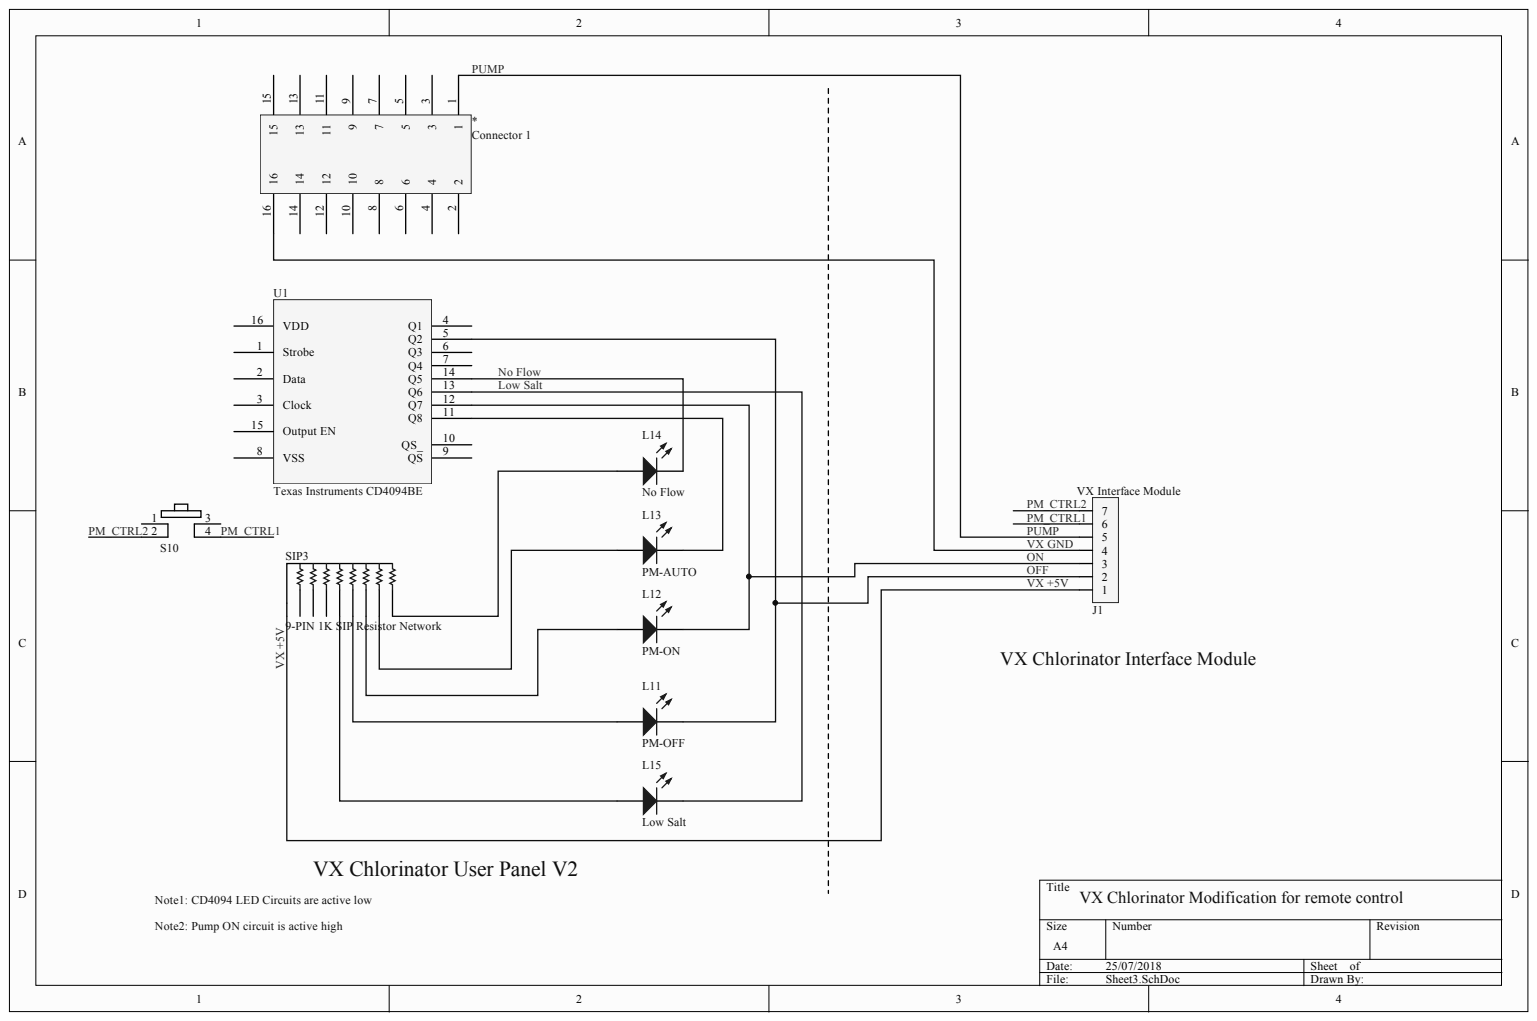
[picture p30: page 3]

No Flow L13

VX GND

PM-AUTO | | ON

OFF

9-PIN 1K SIP Resistor Network

VX Chlorinator Interface Module

VX Chlorinator User Panel V2

Title
VX Chlorinator Modification for remote control

Note1: CD4094 LED Circuits are active low

Note2: Pump ON circuit is active high

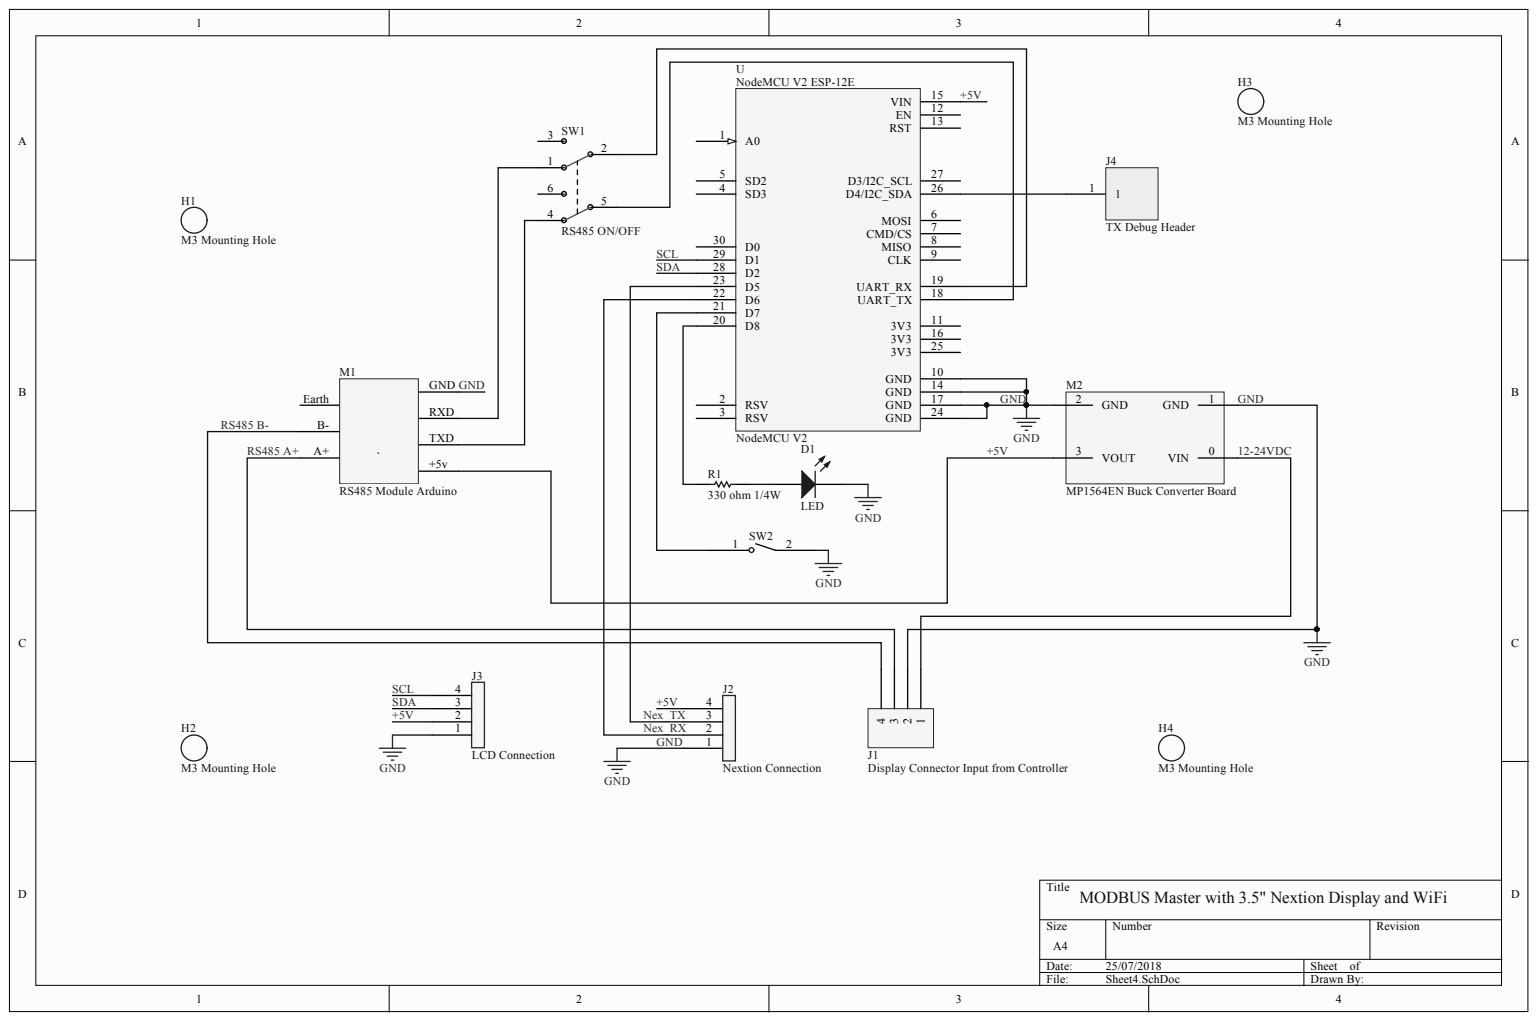
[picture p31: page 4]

RSV 2

Display Connector Input from Controller

Title
MODBUS Master with 3.5" Nextion Display and WiFi

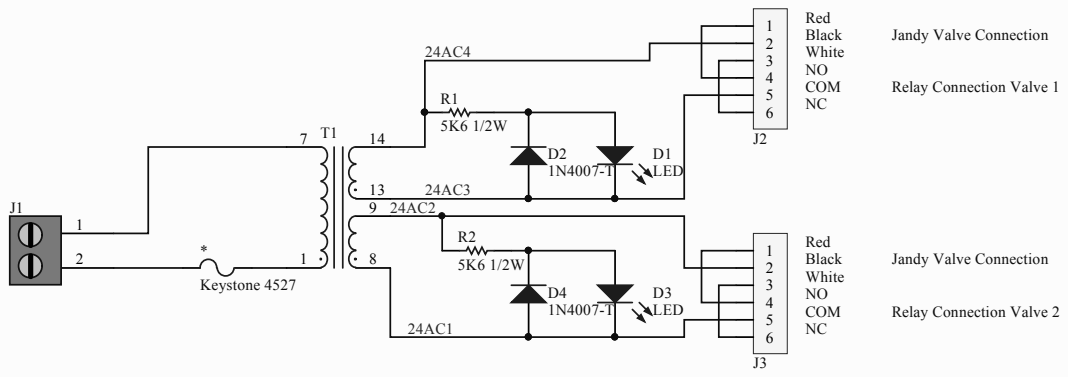
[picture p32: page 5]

Title
2x24VAC Jandy Valve Power Supply

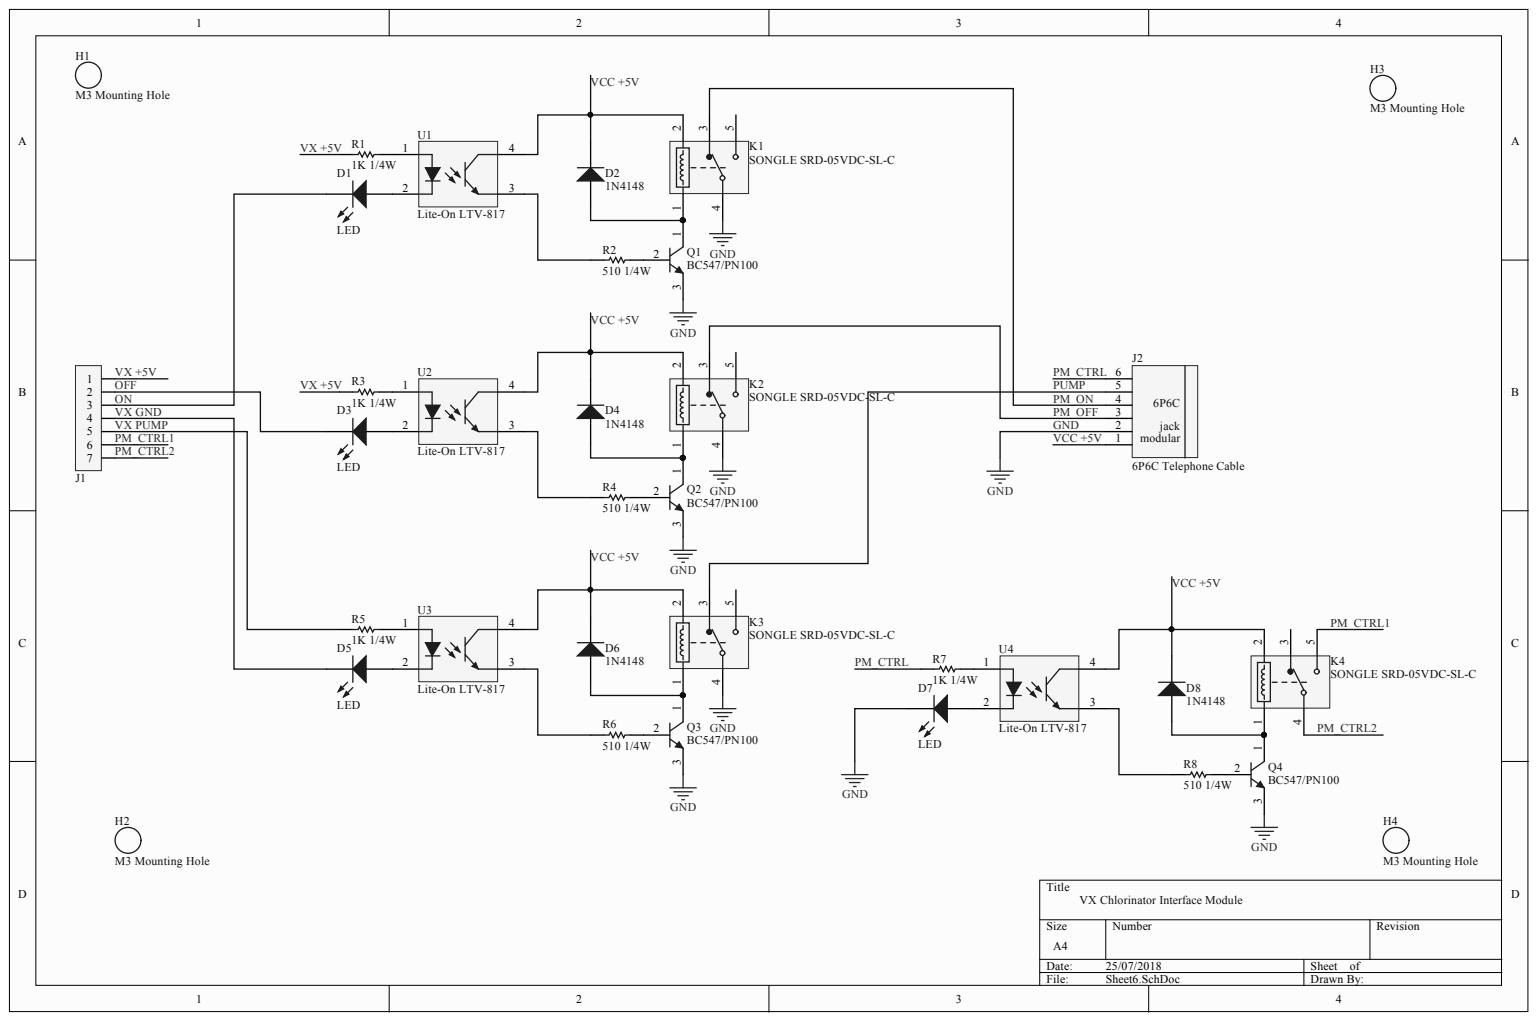
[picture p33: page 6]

Title
VX Chlorinator Interface Module

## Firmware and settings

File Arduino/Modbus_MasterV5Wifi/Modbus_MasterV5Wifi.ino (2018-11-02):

/**
 *  Modbus master for NodeMCU with Nextion Display and LCD Display option.
 *  Alexa support, with Wemo emulator for control and interface to thingspeak for status updates
 * pin maping:
 * 0  - D3 - not used
 * 1  - TX - RS485 (MODBUS)
 * 3  - RX - RS485 (MODBUS)
 * 2  - D4 - BUILTIN_LED. Debug pin for Serial1 TX only.
 * 4  - D2 - I2C SDA (LCD)
 * 5  - D1 - I2C SCL (LCD)
 * 12 - D6 - TX - (SoftwareSerial) to Nextion RX (yellow wire)
 * 14 - D5 - RX - (SoftwareSerial) to Nextion TX (blue wire)
 * 13 - D7 - Trigger Input PIN for configuration of WiFi. 
 * 15 - D8 - Led for WiFi Connected
 * 16 - D0 - Led2 on NodeMCU. Used to indicate main program running. Flash every second. Solid on startup or config mode.
 * 
 */
 
// Modbus Libraries
#include <ESP8266ModbusRtu.h>       // https://github.com/smarmengol/Modbus-Master-Slave-for-Arduino Library modified to run on ESP8266
#define MODBUSID   0                // Modbus Master Address
#define SERIALPORT   0        // serial port: 0-Serial, 1..3-Serial1..Serial3; 4: use software serial
#define TxEnable   0          // flow control pin: 0=USB or RS-232 mode, >0=RS-485 mode
#define BaudRate   9600       // set serial baudrate
#define Parity   SERIAL_8N1   // set serial parity
#define PollRate   350        // set polling rate msec
#define Version   10          // Version Number *10, 10 = Version 1.0
#define TRIGGER_PIN D7        // Trigger PIN to start WiFi Config Portal

// Nextion Libraries
#include <Nextion.h>        // https://github.com/itead/ITEADLIB_Arduino_Nextion
#include <SoftwareSerial.h>                   // Note also need to edit NexConfig.h to match
                                              //#include <SoftwareSerial.h>
                                              //extern SoftwareSerial HMISerial;
                                              //#define nexSerial HMISerial
SoftwareSerial HMISerial(D5, D6, false, 256); // Nextion TX(blue wire) to pin 14(D5) and RX (yellow wire) to pin 12(D6) of NodeMCU

// Libraries for WiFi / Web server
#include <ESP8266WiFi.h>          //https://github.com/esp8266/Arduino
#include <ESP8266WebServer.h>
#include <DNSServer.h>            // Comment out if using ESP8266mDNS.h
//#include <ESP8266mDNS.h>        // Future when mDNS supported on android / MIT AI2 or with Apple iOS (supported now)
#include <WiFiManager.h>          //https://github.com/kentaylor/WiFiManager
#include <ArduinoJson.h>          //https://github.com/bblanchon/ArduinoJson
#include <FS.h>

// LCD Display Libraries
#include <Wire.h> 
#include <LiquidCrystal_I2C.h>
LiquidCrystal_I2C lcd(0x27,20,4); // Check I2C address of LCD, normally 0x27 or 0x3F

                                  // Alexa Belkin Wemo Switch Emulator
#include "WemoSwitch.h"           // Alexa Libraries https://github.com/witnessmenow/esp8266-alexa-wemo-emulator
#include "WemoManager.h"
#include "CallbackFunction.h"

                                  // MQTT Library used to connect to Thingspeak for Alexa
#include <PubSubClient.h>         // https://github.com/knolleary/pubsubclient

// Alexa on/off callbacks
// Can optionally use Wemo switch to toggle the pool mode with either on/off call both active. If use this then MQTT subscribe is not necessary and
// then can remove the PoolModeIntent from the Alexa skill.
//void poolmodeOn();
//void poolmodeOff();
void spaOn();
void spaOff();
void gardenlightOn();
void gardenlightOff();
void poollightOn();
void poollightOff();
// Alexa Wemo Switch constructs
WemoManager wemoManager;
//WemoSwitch *poolmode = NULL;
WemoSwitch *spa = NULL;
WemoSwitch *gardenlight = NULL;
WemoSwitch *poollight = NULL;

// Wifi client for Thinspeak MQTT Connection
WiFiClient espclient;
PubSubClient mqttClient(espclient); // Initialize the PuBSubClient library.

//  
// Prototypes
//

// Handle messages from MQTT subscription.
int mqttSubscriptionCallback(char* topic, byte* payload, unsigned int meslength);  

// Genreate unique Client ID and connect to MQTT broker.
void mqConnect();  

// Subscribe to a field or feed from a ThingSpeak channel.
int mqttSubscribe( String subTopic );

// Publish messages to a channel feed.
void mqttPublish(String pubTopic, String dataString);

// Build a random client ID for MQTT connection
void getID(char clientID[], int idLength);

// Master registers: 
enum {
  SPA_VLV,          // Register 0 Pool/Spa Valve DO
  Spare_VLV,        // Register 1 Spare Valve DO
  Light_1,          // Register 2 Light 1 DO
  Light_2,          // Register 3 Light 2 DO
  PM_Button,        // Register 4 Pool Mode change button
  TIMESCH1,         // Register 5 Time Schedule 1 value
  TIMESCH2,         // Register 6 Time Schedule 2 value
  TIMESCH3,         // Register 7 Time Schedule 3 value
  TIMESCH4,         // Register 8 Time Schedule 4 value
  TIMESCH5,         // Register 9 Time Schedule 5 value  
  Temp_1,           // Register 10 Temperature 1 AI
  Temp_2,           // Register 11 Temperature 2 AI
  Pool_Mode,        // Register 12 Pool Mode Value 0=Auto, 1=ON, 2=OFF, 3=ERROR
  Pump,             // Register 13 Pump Running 0=OFF, 1=ON
  MSG_IN,           // Register 14 Slave Message IN Count
  MSG_OUT,          // Register 15 Slave Message OUT Count
  MSG_ERR,          // Register 16 Slave Message ERROR Count
  Display_Baud,     // Register 17 Slave Device Baud Rate
  Display_ID,       // Register 18 Slave Modubus Slave ID
  Display_Version,  // Register 19 Slave Software Version #
  Master_REGS        // Dummy register. using 0 offset to keep size of array
};

// data array for modbus network sharing
uint16_t au16data[Master_REGS];
uint8_t u8state; //!< machine state
uint8_t u8query; //!< pointer to message query
unsigned long u32wait;
char buffer[10] = {0};  // char buffer for float to string conversion
float Temp1Val; //Temperature 1 value as float
int CurrentPage = 0;  // Create a variable to store which page is currently loaded
unsigned long previousMillis = 0;        // will store last time Nextion was updated
long delayTime = 1000;           // milliseconds of delay-time for Nextion refresh
uint32_t number1 = 0;     // variables to store current values. Only send if values change
uint32_t number2 = 0;
uint16_t old_Temp1 = 0;
uint16_t old_PM = 0;
uint16_t old_Pump = 0;


int ledState = LOW;     // use Builtin LED just to show loop code is running.
unsigned long previousMillis2 = 0;
const long interval = 1000;
String PM_TXT;            // variables for WiFi data
String Pool_TEMP;
String Pool_SPA;
String Pool_PUMP;
String wifitxt = "";
String configtxt = "";
String mactxt = "";
IPAddress myip; // declare the variable
char wifibuf[30] = {0};
char configbuf[30] = {0};
char macbuf[30] = {0};
uint8_t macAddr[6];

// ThingSpeak Settings. This data is set by the wifimanager configuration page
/*
 * Thingspeak Channel 1: Field1 = Pool_Temperature, Field2 = Pool_Mode, Field3 = Spa Status, Field4 = Pump Status
 * example                        22.5                       AUTO/ON/OFF         On/Off               On/Off
 * Thingspeak Channel 2: Field1 = Pool_Mode_Command
 *                                (0 = AUTO, 1=ON, 2=OFF)
 */
char writechannelID[7] = ""; //"123456" Thingspeak Channel 1 number
char readchannelID[7] = ""; //"654321" Thingspeak Channel 2 number
char writeAPIKey[17]  = ""; //"ABCDEF123456ABCD" write API key for your ThingSpeak Channel 1
char readAPIKey[17]  = ""; //"123456ABCDEF1234" read API key for your ThingSpeak Channel 2
char mqttUserName[] = "MQTTDemo-Pool";  // Can be any name.
char mqttPass[17] = ""; //"ABC123DEF456GH78" Change this your MQTT API Key from Account > MyProfile.
const char* mqttserver = "mqtt.thingspeak.com";
String topicString = "";
String data = "";
const int postingInterval = 60 * 1000; // post data every 60 seconds
unsigned long previousMillis3 = 0;
boolean disablecallback = false;
const int disableInterval = 10 * 1000; // disable data for 10 seconds on subscription
unsigned long previousMillis4 = 0;

// WiFi Manager Settings
const char* CONFIG_FILE = "/config.json";
bool initialConfig = false;
bool enableAlexa = false;
// Function Prototypes
bool readConfigFile();
bool writeConfigFile();

// Create an instance of the server
// specify the port to listen on as an argument
WiFiServer server(81);

/**
 *  Modbus object declaration
 *  u8id : node id = 0 for master, = 1..247 for slave
 *  u8serno : serial port (use 0 for Serial)
 *  u8txenpin : 0 for RS-232 and USB-FTDI 
 *               or any pin number > 1 for RS-485
 */
Modbus master(MODBUSID,SERIALPORT,TxEnable); // this is master and RS-232 or USB-FTDI
/**
 * This is an structe which contains a query to an slave device
 */
modbus_t telegram[2];   // Number of MODBUS telegrams defined here

/*
 * Nextion Declarations
 * Declare a button object [page id:0,component id:1, component name: "b0"]. 
 */
NexPicture p4 = NexPicture(0, 41, "p4");
NexText t0 = NexText(0, 1, "t0");
NexText t1 = NexText(0, 2, "t1");
NexPicture p5 = NexPicture(0, 42, "p5");
NexText Ctxt = NexText(1, 16, "Ctxt");
NexText Wtxt = NexText(1, 17, "Wtxt");
NexText stxt = NexText(1, 18, "stxt");
NexText atxt = NexText(1, 19, "atxt");
NexPicture p0 = NexPicture(0, 3, "p0");
NexPicture p1 = NexPicture(0, 4, "p1");
NexPicture p2 = NexPicture(0, 5, "p2");
NexNumber n0 = NexNumber(1, 2, "n0");
NexNumber n1 = NexNumber(1, 3, "n1");
NexNumber n2 = NexNumber(1, 4, "n2");
NexNumber n3 = NexNumber(1, 5, "n3");
NexNumber n4 = NexNumber(1, 6, "n4");
NexNumber n5 = NexNumber(1, 7, "n5");
NexVariable gsched1 = NexVariable(0, 30, "gsched1");
NexVariable gsched2 = NexVariable(0, 49, "gsched2");
NexPage page0 = NexPage(0, 0, "page0");  // Page added as a touch event
NexPage page1 = NexPage(1, 0, "page1");  // Page added as a touch event

/*
 * Nextion touch events
 * Register object to the touch event list.  
 */
NexTouch *nex_listen_list[] = 
{
    &p4,
    &p0,
    &p1,
    &p2,
    &page0,  // Page added as a touch event
    &page1,  // Page added as a touch event
    &gsched1,  // Timer1 on/off change added as event
    &gsched2,  // Timer2 on/off change added as event
    NULL
};

/*
 * Nextion Callbacks
 * Button0 component pop callback function.
 * In this example,the value of the number component will plus one every time when button0 is released.
 */
// Callback event when timer1 changes.
void gsched1PopCallback(void *ptr)
{
    //Serial.println("gsched1PopCallback");
    gsched1.getValue(&number1);
    au16data[TIMESCH1] = number1;
}
// Callback event when timer2 changes.
void gsched2PopCallback(void *ptr)
{
    //Serial.println("gsched2PopCallback");
    gsched2.getValue(&number2);
    au16data[TIMESCH2] = number2;
}
// Callback event for Pool Mode Pushbutton
void p4PopCallback(void *ptr)
{
    //Serial.println("p4PopCallback");
    au16data[PM_Button] = 1;    
}
// Callback event for Pool/SPA valve Pushbutton
void p0PopCallback(void *ptr)
{
    uint32_t number = 0;
    //Serial.println("p0PopCallback");
    p0.getPic(&number);
    if (number == 1)
    {
        number = 2;
        au16data[SPA_VLV] = 1;    
    }
    else
    {
        number = 1;
        au16data[SPA_VLV] = 0;
    }
    p0.setPic(number);
}
// Callback event for Light 1 Pushbutton
void p1PopCallback(void *ptr)
{
    uint32_t number = 0;
    //Serial.println("p1PopCallback");
    p1.getPic(&number);
    if (number == 3)
    {
        number = 4;
        au16data[Light_1] = 1;    
    }
    else
    {
        number = 3;
        au16data[Light_1] = 0;
    }
    p1.setPic(number);
}
// Callback event for Light 2 Pushbutton
void p2PopCallback(void *ptr)
{
    uint32_t number = 0;
    //Serial.println("p2PopCallback");
    p2.getPic(&number);
    if (number == 3)
    {
        number = 4;
        au16data[Light_2] = 1;    
    }
    else
    {
        number = 3;
        au16data[Light_2] = 0;
    }
    p2.setPic(number);
}
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
void loop(void)
{   
    nexLoop(nex_listen_list);

    // is configuration portal requested?
    // use configuration portal if requested by trigger pin
    if ( digitalRead(TRIGGER_PIN) == LOW ) {
      Serial1.println("Configure WiFi connection now");
      digitalWrite(D0, LOW);  // set the configuration LED to on.

      // Extra parameters to be configured
      // After connecting, parameter.getValue() will get you the configured value
      // Format: <ID> <Placeholder text> <default value> <length> <custom HTML> <label placement>

      // Thingspeak API Key - this is a straight forward string parameter
      WiFiManagerParameter p_thingspeakApiKey("thingspeakapikey", "Thingspeak API Key", writeAPIKey, 17);
      // Thingspeak Write Channel ID - this is a straight forward string parameter
      WiFiManagerParameter p_thingspeakchannel1("thingspeakchannel1", "Thingspeak Write Channel", writechannelID, 7);
      // Thingspeak Read Channel ID - this is a straight forward string parameter
      WiFiManagerParameter p_thingspeakchannel2("thingspeakchannel2", "Thingspeak Read Channel", readchannelID, 7);
      // Thingspeak MQTT Key - this is a straight forward string parameter
      WiFiManagerParameter p_thingspeakMQTTkey("thingspeakmqttkey", "Thingspeak MQTT Key", mqttPass, 17);

      // enableAlexa or not - bool parameter visualized using checkbox, so couple of things to note
      // - value is always 'T' for true. When the HTML form is submitted this is the value that will be 
      //   sent as a parameter. When unchecked, nothing will be sent by the HTML standard.
      // - customhtml must be 'type="checkbox"' for obvious reasons. When the default is checked
      //   append 'checked' too
      // - labelplacement parameter is WFM_LABEL_AFTER for checkboxes as label has to be placed after the input field

      char customhtml[24] = "type=\"checkbox\"";
      if (enableAlexa) {
        strcat(customhtml, " checked");
      }
      WiFiManagerParameter p_enableAlexa("enableAlexa", "Alexa Enable", "T", 2, customhtml, WFM_LABEL_AFTER);

      // Just a quick hint
      WiFiManagerParameter p_hint("<small>*Hint: if you want to reuse the currently active WiFi credentials, leave SSID and Password fields empty</small>");
            
      //WiFiManager
      //Local intialization. Once its business is done, there is no need to keep it around
      WiFiManager wifiManager;
      wifiManager.setDebugOutput(false);  // disable WM: debug messages
      //reset settings - for testing
      //wifiManager.resetSettings();

      //sets timeout until configuration portal gets turned off
      //useful to make it all retry or go to sleep
      //in seconds
      wifiManager.setConfigPortalTimeout(180);

      //add all parameters here
    
      wifiManager.addParameter(&p_hint);
      wifiManager.addParameter(&p_thingspeakApiKey);
      wifiManager.addParameter(&p_thingspeakchannel1);
      wifiManager.addParameter(&p_thingspeakchannel2);
      wifiManager.addParameter(&p_thingspeakMQTTkey);
      wifiManager.addParameter(&p_enableAlexa);

      //it starts an access point with the specified name
      //here  "AutoConnectAP"
      //and goes into a blocking loop awaiting configuration

      //WITHOUT THIS THE AP DOES NOT SEEM TO WORK PROPERLY WITH SDK 1.5 , update to at least 1.5.1
      //WiFi.mode(WIFI_STA);
      if (!wifiManager.startConfigPortal("LeisureAP")) {
        //Serial.println("Configuration Failed / Timeout");
        configtxt = "Configure WiFi Failed"; 
        delay(3000);
        //reset and try again, or maybe put it to deep sleep
        //ESP.reset();
        //delay(5000);
      }

      //if you get here you have connected to the WiFi
      else {
        // Getting posted form values and overriding local variables parameters
        // Config file is written regardless the connection state
        strcpy(writeAPIKey, p_thingspeakApiKey.getValue());
        strcpy(writechannelID, p_thingspeakchannel1.getValue());
        strcpy(readchannelID, p_thingspeakchannel2.getValue());
        strcpy(mqttPass, p_thingspeakMQTTkey.getValue());
        enableAlexa = (strncmp(p_enableAlexa.getValue(), "T", 1) == 0);
        writeConfigFile();
        //Serial.print("API Key is : ");
        //Serial.println(writeAPIKey);
        //Serial.print("Channel1 is : ");
        //Serial.println(writechannelID);
        //Serial.print("Channel2 is : ");
        //Serial.println(readchannelID);
        //Serial.print("Enable Alexa is : ");
        //Serial.println(enableAlexa);
        Serial1.println("Configuration Complete");
      }
      ESP.reset(); // This is a bit crude. For some unknown reason webserver can only be started once per boot up 
      // so resetting the device allows to go back into config mode again when it reboots.
      delay(5000);
    
    } 

    // Alexa Wemo Manager. Only run wemo serverloop if Alexa option is enabled.
    if (enableAlexa == true) wemoManager.serverLoop();

    // Cycle Builtin LED to show main program running
    unsigned long currentMillis = millis();
    if(currentMillis - previousMillis2 >= interval) {
      previousMillis2 = currentMillis;   
      if (ledState == LOW)
        ledState = HIGH;  // Note that this switches the LED *off*
      else
        ledState = LOW;   // Note that this switches the LED *on*
      digitalWrite(D0, ledState);
    }
    
    // D8 used to show WiFi connection is good.
    if (WiFi.status() == WL_CONNECTED) digitalWrite(D8, HIGH);
    else digitalWrite(D8, LOW);  
    
    // MODBUS Master. This cycles the modbus messages and polls for the responses.
    switch( u8state ) {
    case 0: 
      if (millis() > u32wait) u8state++; // wait state
      break;
    case 1:   
      master.query( telegram[u8query] ); // send query (only once)
      u8state++;
      // The Pool Mode button value is reset to 0 when the message is sent. This simulates a momentary button but also allows multiple pulses when the value is > 1.
      // For the Alexa skill a value of 2 is needed.
      if ((u8query == 1) && (au16data[PM_Button] >= 1)) au16data[PM_Button] =0; // reset PM_Button to 0 only once telegram is sent
    u8query++;
    if (u8query == 2) u8query = 0;
      break;
    case 2:
      master.poll(); // check incoming messages
      if (master.getState() == COM_IDLE) {
        u8state = 0;
        u32wait = millis() + PollRate; // After message response reset the delay before new message is sent (ie modbus nessage cycle time)
      }
      break;
    }
    
     /* NEXTION Display
     * When a pop or push event occured every time, 
     * the corresponding component[right page id and component id] in touch event list will be asked.
     * The delay time of 1000ms is used to limit the data being sent to nextion and avoid conflict with touch events
     */
    
    if((millis() - previousMillis >= delayTime)) {
  
      previousMillis = millis();  // Remember the time
    
      if(CurrentPage == 0){  // If the display is on page 0, do the following:
        memset (buffer, 0, sizeof(buffer));
        //au16data[Temp_1] = random(100,300);           // test value
        if (au16data[Temp_1] != old_Temp1) {              // only send data if it has changed value
          Temp1Val = (au16data[Temp_1]) / 10.0;           // convert MODBUS integer to float
          dtostrf(Temp1Val, 4, 1, buffer);                // convert float to string with, min 4 char, 1 decimal point
          t1.setText(buffer);                             // send temperature value string to t1
          old_Temp1 = au16data[Temp_1];
          Pool_TEMP = buffer;
        }        
        //au16data[Pool_Mode] = random(0,3);          // test value
        if (au16data[Pool_Mode] != old_PM) {              // only send data if it has changed value
          if (au16data[Pool_Mode] == 0) {
            t0.setText("AUTO");
            PM_TXT = "AUTO";
          }
          if (au16data[Pool_Mode] == 1) {
            t0.setText("ON");
            PM_TXT = "ON";
          }
          if (au16data[Pool_Mode] == 2) { 
            t0.setText("OFF");
            PM_TXT = "OFF";
          }
          if (au16data[Pool_Mode] == 3) { 
            t0.setText("ERROR");
            PM_TXT = "ERROR";
          }
          old_PM = au16data[Pool_Mode];
        }
        if (au16data[Pump] != old_Pump) {              // only send data if it has changed value
          if (au16data[Pump] == 0) sendCommand("p5.pic=9");
          if (au16data[Pump] == 1) sendCommand("p5.pic=10");
          old_Pump = au16data[Pump];
        }
        if (au16data[SPA_VLV] == 1) Pool_SPA = "on";
        else Pool_SPA = "off";
        if (au16data[Pump] == 1) Pool_PUMP = "on";
        else Pool_PUMP = "off";
      }
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

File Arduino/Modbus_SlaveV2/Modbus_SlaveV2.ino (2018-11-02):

 /**
 *  Modbus slave for arduino uno
 * pin maping:
 * 0 - RX
 * 1 - TX
 * 2 - TxEnable
 * 3 - digital output
 * 4 - digital output
 * 5 - digital output
 * 6 - digital output
 * 7 - digital output
 * 8 - digital input
 * 9 - digital input
 * 10 - digital input
 * 11 - digital input
 * 12 - analog input - Datawire type temperature
 * 13 - analog input - Datawire type temperature
 * 
 * A0 - analog input - Thermistor type temperature
 * A1 - analog input - Thermistor type temperature
 */

#include <ModbusRtu.h>
#define ID   1                // Modbus Slave Address
#define SERIALPORT   0        // serial port: 0-Serial, 1..3-Serial1..Serial3; 4: use software serial
#define TxEnable   0          // flow control pin: 0=USB or RS-232 mode, >0=RS-485 mode
#define BaudRate   9600       // set serial baudrate
#define Parity   SERIAL_8N1   // set serial parity
#define Version   10          // Version Number *10, 10 = Version 1.0

  //  Setup using Thermistor type temperature on Arduino analog inputs
#include <math.h>         // loads the more advanced math functions - comment out if using Data Wire
#define filter  0.01        // set filter weight >0 and <=1. This sets the filter for the temperature sensor 0.5 is average

  // Setup using Data wire is plugged into pin 12,13 on the Arduino for temperature inputs
//#include <DallasTemperature.h>    // Comment out if using Thermistor
//#include <OneWire.h>
//#define ONE_WIRE_BUSA 12  // Temperature 1 AI
//#define ONE_WIRE_BUSB 13  // Temperature 2 AI

  // Setup a oneWire instance to communicate with any OneWire devices (not just Maxim/Dallas temperature ICs)
//OneWire oneWireA(ONE_WIRE_BUSA);
//OneWire oneWireB(ONE_WIRE_BUSB);
  // Pass our oneWire reference to Dallas Temperature. 
//DallasTemperature sensorsA(&oneWireA);
//DallasTemperature sensorsB(&oneWireB);

// Create new modbus instance
Modbus slave(ID, SERIALPORT, TxEnable); // this is slave ID and RS-232 or USB-FTDI

// Slave registers: Note Digital IN/OUT have to be the first registers
enum {
  Digital_IN,       // Register 0 PM_OFF Bit 0, PM_ON Bit 1, PUMP Bit 2
  Digital_OUT,      // Register 1 Not used - using registers for DO instead of coils.
  PM_CTRL,          // Register 2 Pool Mode DO
  SPA_VLV,          // Register 3 Pool/Spa Valve DO
  Spare_VLV,        // Register 4 Spare Valve DO
  Light_1,          // Register 5 Light 1 DO
  Light_2,          // Register 6 Light 2 DO
  PM_Button,        // Register 7 Pool Mode change button
  TIMESCH1,         // Register 8 Time Schedule 1 value
  TIMESCH2,         // Register 9 Time Schedule 2 value
  TIMESCH3,         // Register 10 Time Schedule 3 value
  TIMESCH4,         // Register 11 Time Schedule 4 value
  TIMESCH5,         // Register 12 Time Schedule 5 value  
  Temp_1,           // Register 13 Temperature 1 AI
  Temp_2,           // Register 14 Temperature 2 AI
  Pool_Mode,        // Register 15 Pool Mode Value 0=Auto, 1=ON, 2=OFF, 3=ERROR
  Pump,             // Register 16 Pump Running 0=OFF, 1=ON
  MSG_IN,           // Register 17 Message IN Count
  MSG_OUT,          // Register 18 Message OUT Count
  MSG_ERR,          // Register 19 Message ERROR Count
  Display_Baud,     // Register 20 Device Baud Rate
  Display_ID,       // Register 21 Modubus Slave ID
  Display_Version,  // Register 22 Software Version #
  Slave_REGS        // Dummy register. using 0 offset to keep size of array
};

// data array for modbus network sharing
uint16_t au16data[Slave_REGS];

unsigned long previousMillis = 0;        // will store last time LED was updated
long OnTime = 250;           // milliseconds of on-time
long OffTime = 250;          // milliseconds of off-time
unsigned long previousMillis2 = 0;        // will store last time temperature was updated
long delayTime = 1000;           // milliseconds of delay-time for temperature refresh
int averagetemp1 = 0;        // average temp1 reading
//int averagetemp2 = 0;        // average temp2 reading

/**
 *  Setup procedure
 */
void setup() {
    // define i/o
  pinMode(TxEnable,OUTPUT);      //   TxEnable Control for RS485  
  pinMode(3,OUTPUT);      //   PM_CTRL - Pool Mode DO
  pinMode(4,OUTPUT);      //   SPA_VLV - Pool/Spa Valve DO
  pinMode(5,OUTPUT);      //   Spare_VLV - Spare Valve DO
  pinMode(6,OUTPUT);      //   Light_1 - Light_1 DO
  pinMode(7,OUTPUT);      //   Light_2 - Light_2 DO
  pinMode(8,INPUT_PULLUP);  //  PM_OFF - DI
  pinMode(9,INPUT_PULLUP);  //  PM_ON - DI
  pinMode(10,INPUT_PULLUP); //  PUMP - DI
  pinMode(11,INPUT_PULLUP); //  Not used - DI

 // start communication
  //Serial.begin(9600); //Begin serial communication
  slave.begin( BaudRate, Parity );  // set slave baudrate, parity
  averagetemp1 = analogRead(0);     // set initial value for first analog read of sensor
  //averagetemp2 = analogRead(1);
}

  //  Setup using Thermistor type temperature on Arduino analog inputs - comment out if using Data Wire
  //Function to perform the fancy math of the Steinhart-Hart equation
  // RawADC is the raw analogread() value.
  // nomRes is the thermistor nominal resistance, usually 10000
  // bCoef is the thermistor beta coefficient, usually 3950 for a 10K thermistor
  // serialRes is the actual series resistor value, nominally 10000
float Thermistor (uint16_t RawADC, uint16_t nomRes, uint16_t bCoef, uint16_t serialRes) {
#define ADC_RESOLUTION 1023
#define TEMPERATURENOMINAL 25
  float tempval = 0;

  tempval = RawADC;
  //Serial.print("Raw analog reading "); 
  //Serial.println(RawADC);

  // convert the value to resistance
  tempval = ADC_RESOLUTION / tempval - 1;
  tempval = serialRes * tempval;
  //Serial.print("Thermistor resistance "); 
  //Serial.println(tempval);
 
  float steinhart;
  steinhart = tempval / nomRes;     // (R/Ro)
  steinhart = log(steinhart);                  // ln(R/Ro)
  steinhart /= bCoef;                   // 1/B * ln(R/Ro)
  steinhart += 1.0 / (TEMPERATURENOMINAL + 273.15); // + (1/To)
  steinhart = 1.0 / steinhart;                 // Invert
  steinhart -= 273.15;                         // convert to C
  //Serial.print("Temperature "); 
  //Serial.print(steinhart);
  //Serial.println(" *C");
   
  return steinhart;
}
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
